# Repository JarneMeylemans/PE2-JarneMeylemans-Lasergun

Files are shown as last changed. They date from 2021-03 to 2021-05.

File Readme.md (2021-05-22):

# Practice Enterprise 2: Lasergun

Jarne Meylemans 

(Finale code staat onder 'Project_Code/STM32F4/PE_LASERGUN_CODE_2apr')

## Korte Beschrijving

Het doel van dit project zal zijn te weten komen hoe een lasergun kan werken. Het geweer zal moeten kunnen een infrarood signaal sturen waarmee het bekend maakt wie het is (Elk geweer heeft zo zijn eigen "code". Elke Lasergun zal met een centraal punt kunnen communiceren om een score bij te houden van het houdige spelletje. 

Via een scherm kan de speler zien hoeveel kogels hij nog heeft en wat zijn score is in het spel. 

## Hardware

Om het lasergeweer te maken heb ik gekozen om met de STM32F410 microcontroller te werken, deze stuurt alles aan als volgt: 

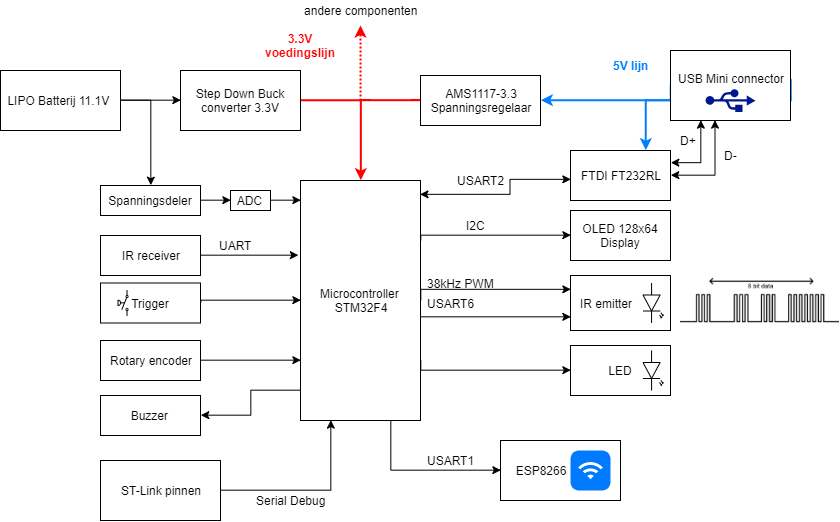
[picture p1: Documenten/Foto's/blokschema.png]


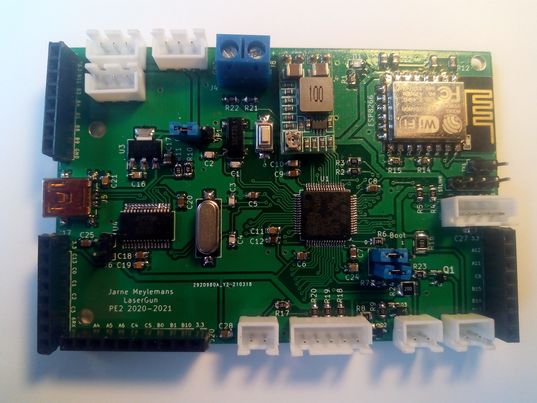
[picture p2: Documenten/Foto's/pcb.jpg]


## Software 

Met de software heb ik geprobeerd om een soort State Machine te programmeren zodat er makkelijk kan veranderd worden van functie waar we inzitten

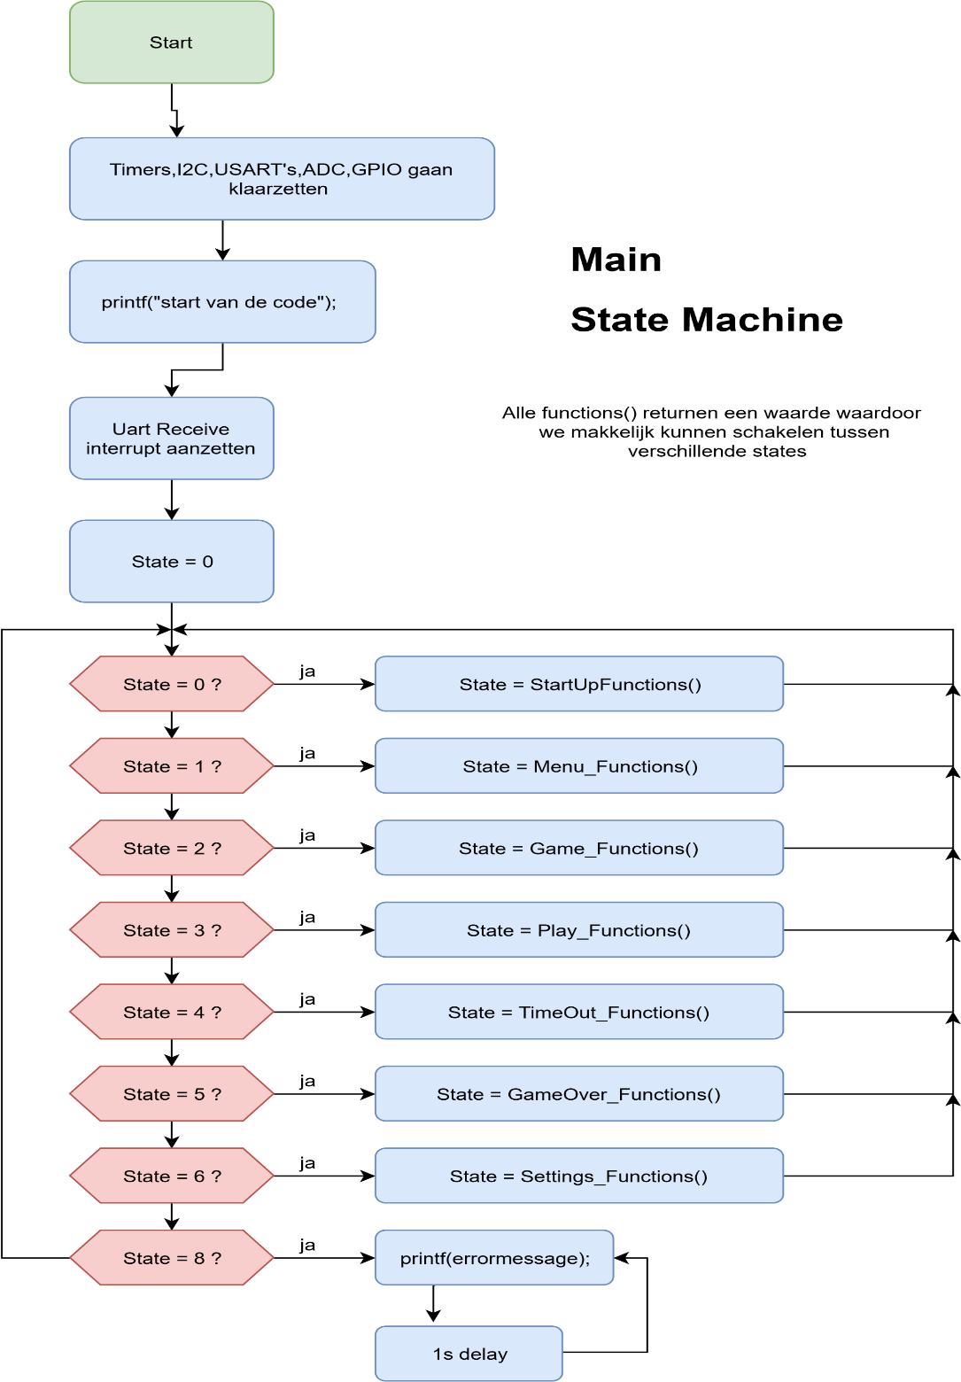
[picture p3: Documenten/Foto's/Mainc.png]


## Behuizing

De behuizing is getekend in fusion 360 en is geprint met een 3D printer, de behuizing bestaat uit 11 verschillende stukken. 

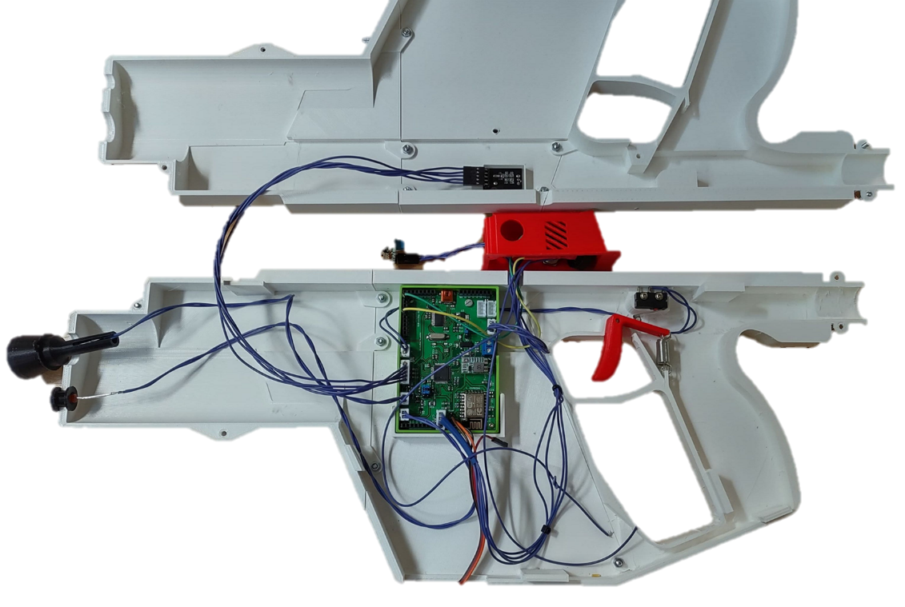
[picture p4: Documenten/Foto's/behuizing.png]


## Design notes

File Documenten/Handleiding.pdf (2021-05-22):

# Lasergeweer: Handleiding

### 1.Aanzetten van het lasergeweer

Er zijn twee opties om het geweer aan te voeding te geven, de eerste is door langs de onderkant de batterij aan te sluiten, de tweede is via een externe powerbank aan te sluiten aan de usb connectie bovenaan het geweer.

Opmerking: Het lasergeweer kan niet meteen afwisselend batterijspanning of USB spanning gebruiken. Om te wisselen tussen spanningsbron is het nodig om het lasergeweer open te schroeven, de blauwe jumper dient naar een andere pin worden gezet.

### 1a. Via batterij

Onderaan het geweer kan de aansluiting van de batterij worden gevonden. Aan de gele XT60 connector kan de batterij worden aangesloten.

Nadien kan de powerswitch gesloten worden om het lasergeweer spanning te geven, deze switch staat bovenaan het lasergeweer.

### 1b. Via USB

Bovenaan het geweer, achter het vizier bevindt zich een mini USB connector. Plug de USB kabel in het lasergeweer, zorg er ook voor dat de USB kabel ook is ingeplugd in een externe powerbank.

### 2. Lasergeweer resetten

Voordat er een spel gestart kan worden moet het lasergeweer even gereset worden. Dit kan door met een dun langwerpige schroevendraaier op de reset knop te drukken.

### 3. Een spel starten

Na het indrukken van de reset knop wordt het startscherm getoond. Om verder te gaan naar het menu dient de rotary encoder switch worden ingedrukt.

In het menu kan er gekozen worden voor 3 dingen, Settings, Play en Exit. Onder het menu ‘settings’ kunnen er enkele parameters aangepast worden voor tijdens het spel. Door ‘Play’ te kiezen wordt het spel gestart. ‘Exit’ gaat je terugbrengen naar het startscherm.

Parameters aanpassen

Onder het settings menu kan de ‘demage’ (schade punten) aangepast worden door de Trigger ingedrukt te houden en aan de rotary encoder te draaien.

Op diezelfde manier kan IR worden aangepast. IR zelf is de ID nummer van het lasergeweer, op die manier kan er gekozen worden of de spelers in teams spelen of individueel. Bij elke ID hoort ook een naam.

### 4. Het spel spelen

Nadat er in het menu gekozen werd voor ‘Play’ gaat het spel opstarten.

De interface tijdens het spelen ziet er als volgt uit

1. Schieten met het lasergeweer kan door de rode trigger over te halen tijdens het spelen.
2. Herladen kan door aan de rotary encoder een bepaalde hoek te draaien, op die manier kunnen er kogels bijgemaakt worden in het geweer.
3. Het spel vroegtijdig afsluiten kan door tijdens het spel op de rotary encoder te klikken.

OLED

Trigger

Rotary
encoder

IR LED

IR ontvanger

Wanneer een speler geraakt is zal het lasergeweer op de display dit tonen samen met een timer van 10 seconden, de speler zal 10 seconden uit het spel liggen, Op het scherm komt te staan door wie je geraakt bent en hoeveel HP er nog over is. Op dat moment word de demage afgetrokken van de huidige HP, wanneer de speler geen Health points meer heeft is het spel voorbij en komt er ‘GAME OVER’ op het scherm.

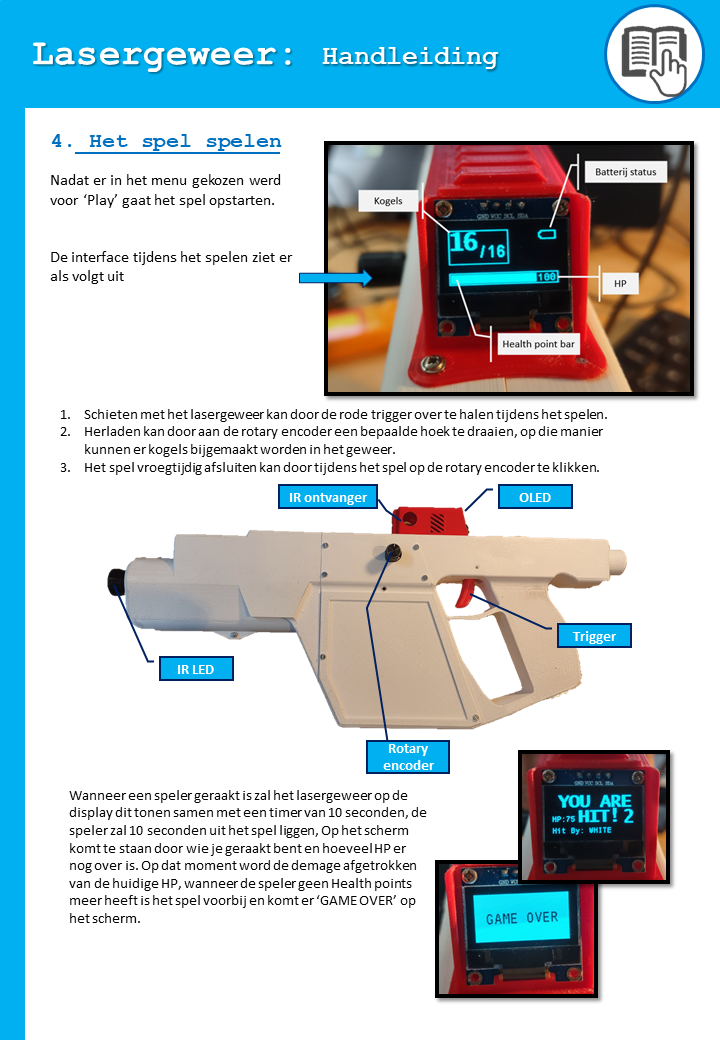
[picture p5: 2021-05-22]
Documenten/Handleiding/Dia3.PNG

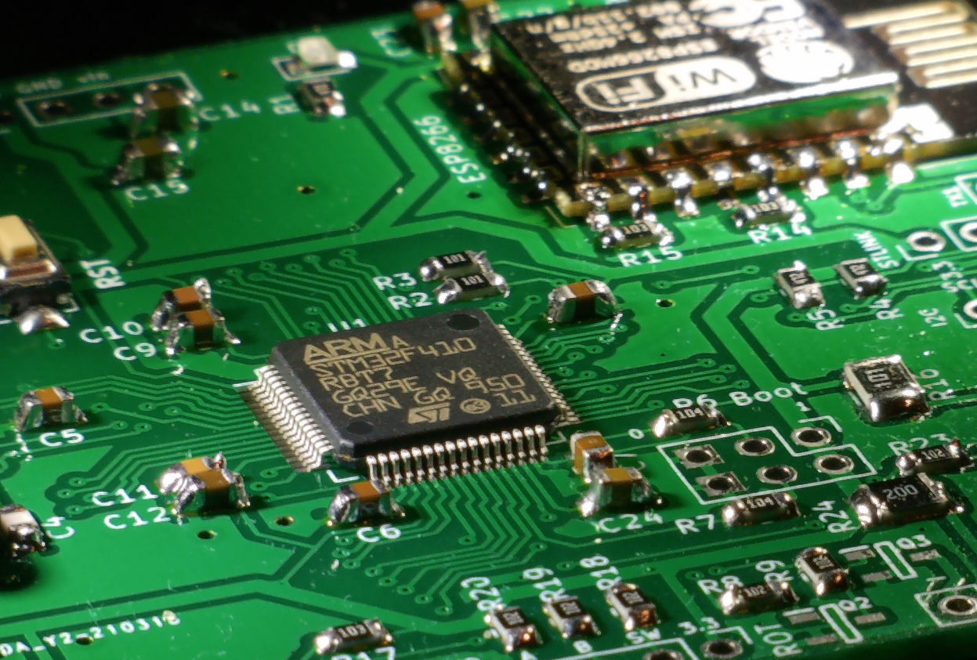
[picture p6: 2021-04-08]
Documenten/Foto's/pcb2.png

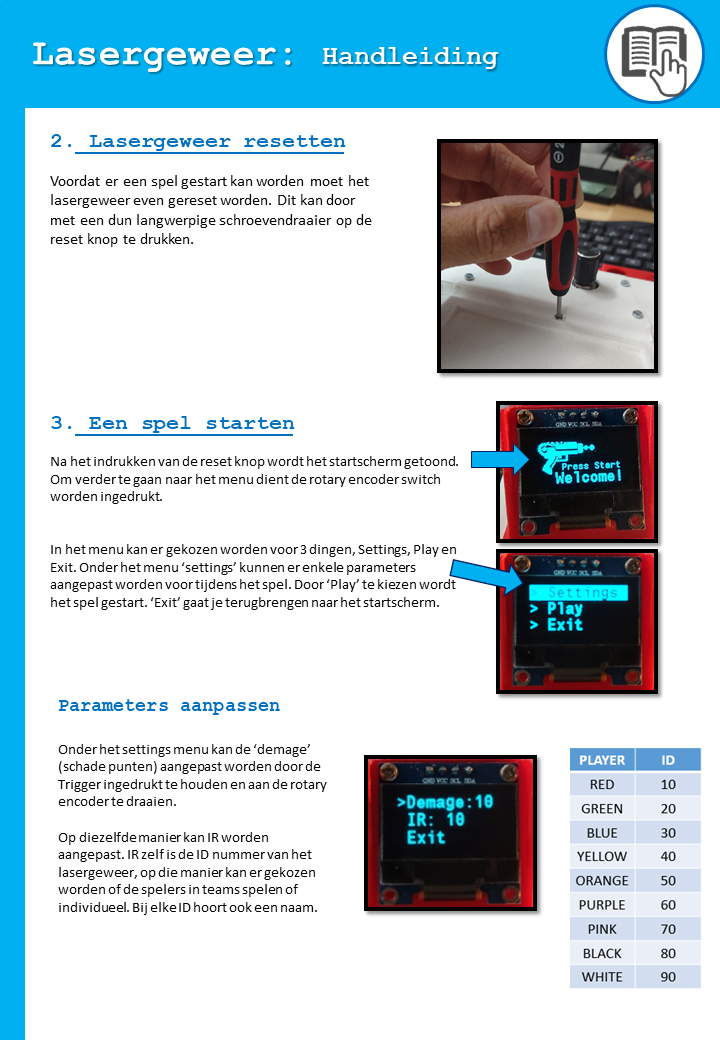
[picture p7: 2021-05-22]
Documenten/Handleiding/Dia2.PNG

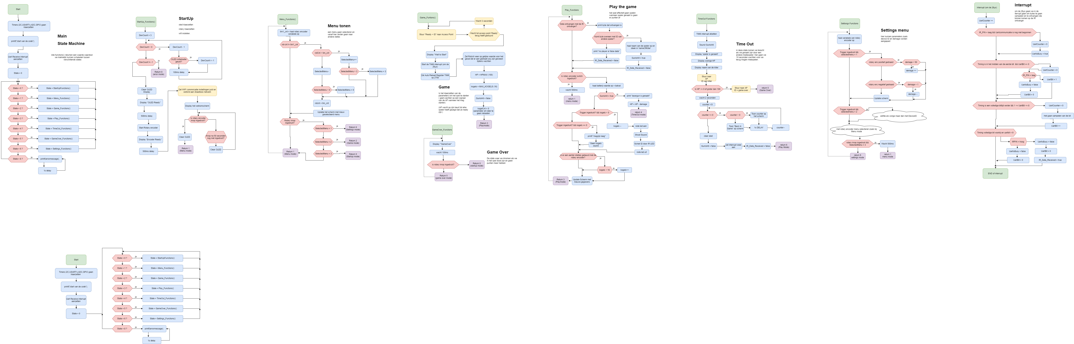
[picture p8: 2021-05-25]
Documenten/SoftwareBlokschema's.png

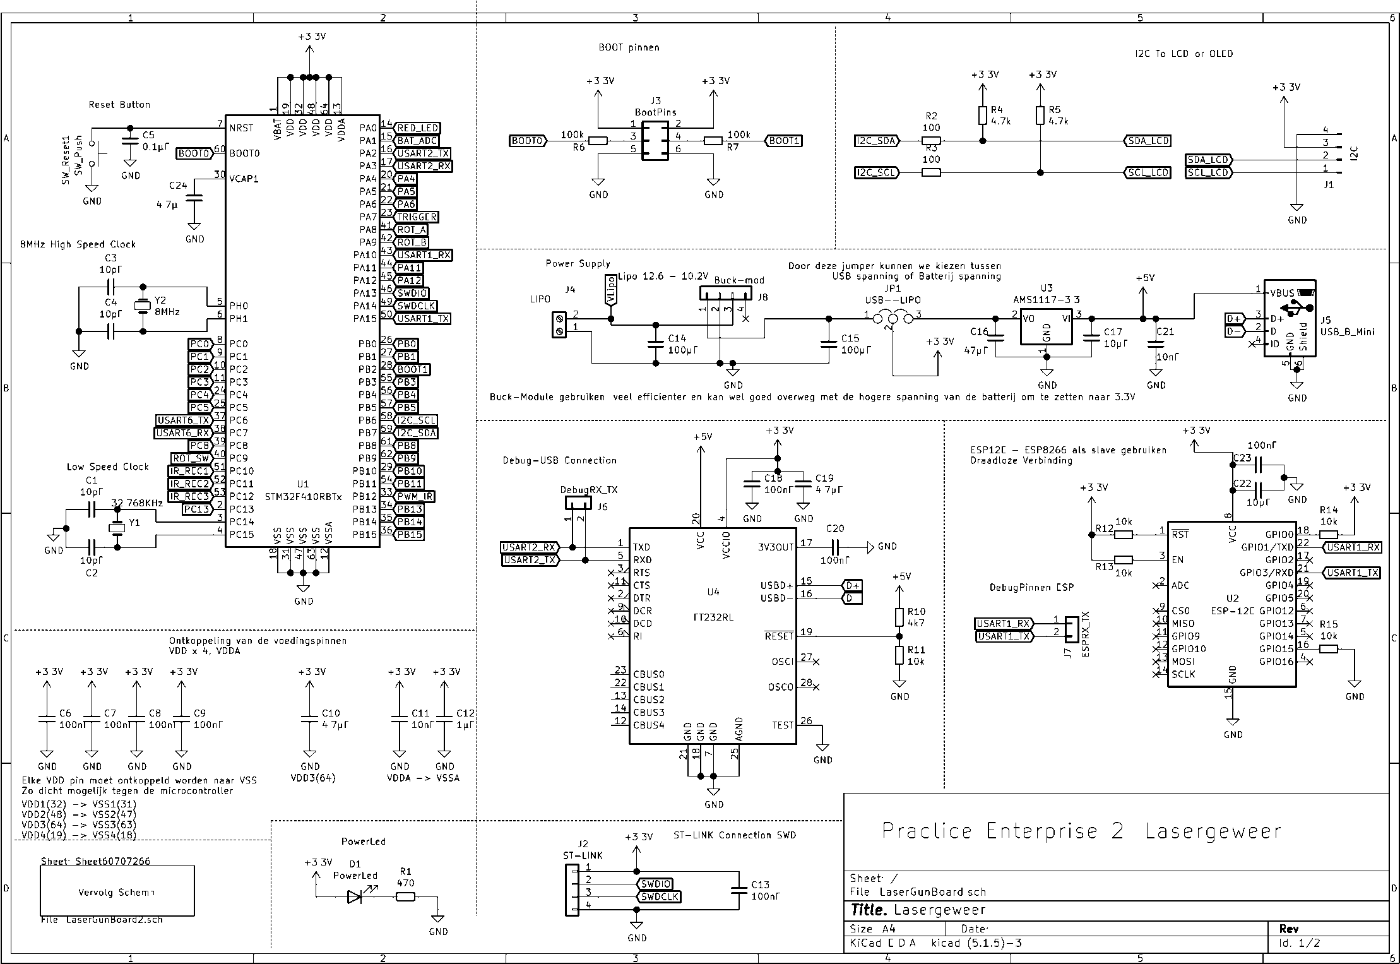
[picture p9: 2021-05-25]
Documenten/Foto's/schema.png

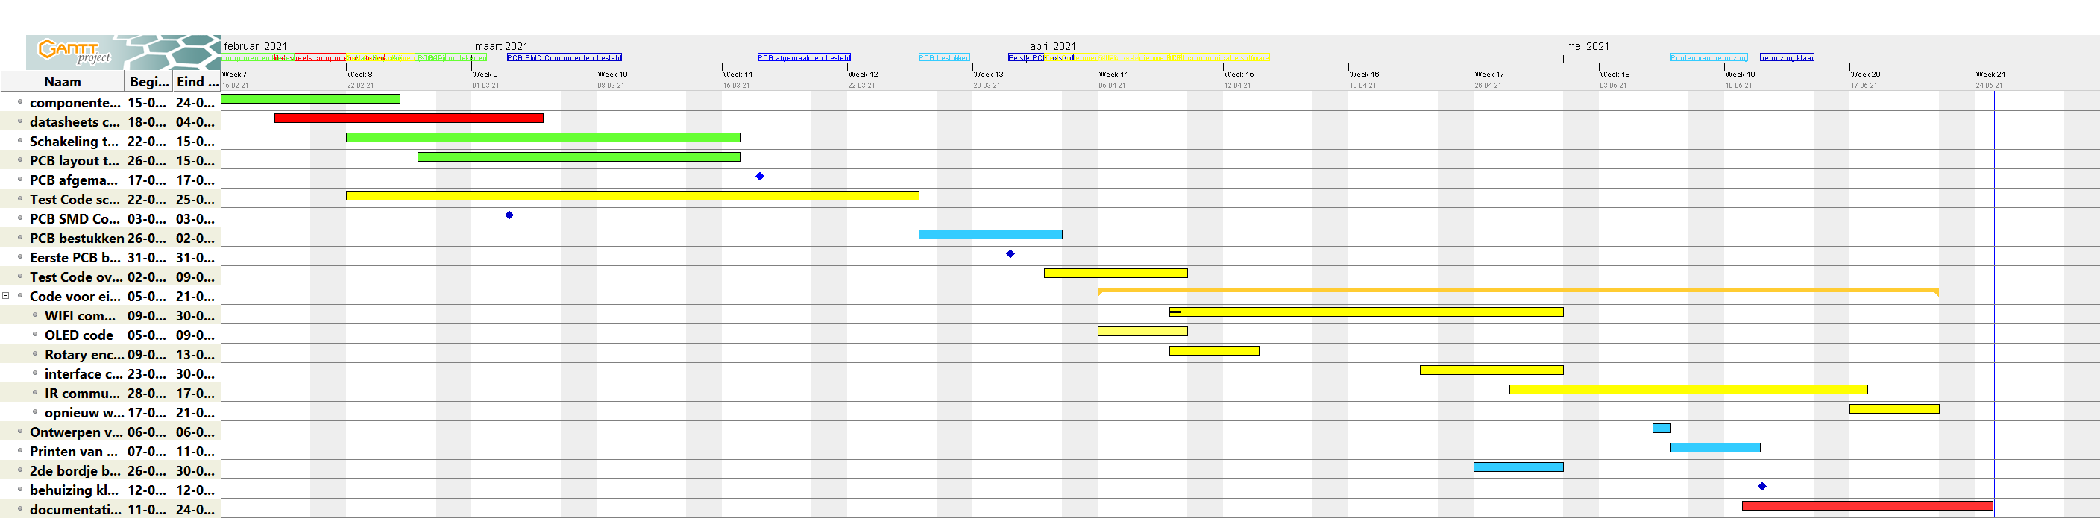
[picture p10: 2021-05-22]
Documenten/gantt/pe2.png

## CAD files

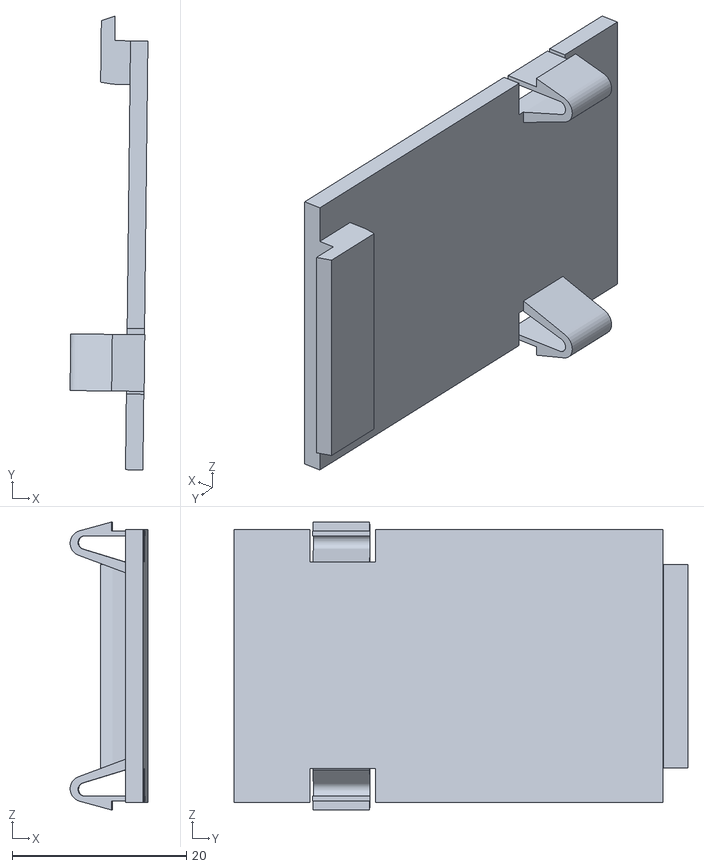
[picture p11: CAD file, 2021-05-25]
3D-tekeningen/batterycover.stl
8.93 x 52.0 x 33.0

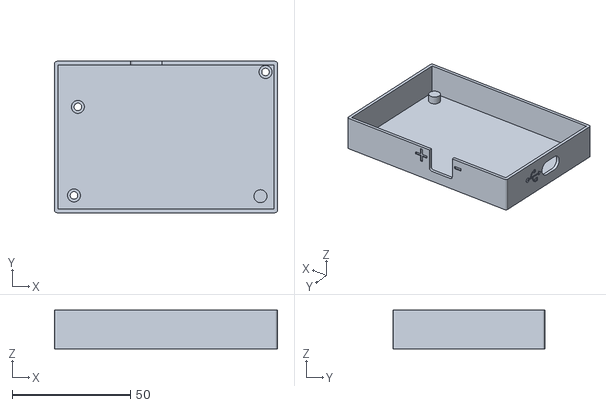
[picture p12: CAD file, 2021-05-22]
3D-tekeningen/LaserBoard_Box.stl
94.2 x 64.0 x 16.3

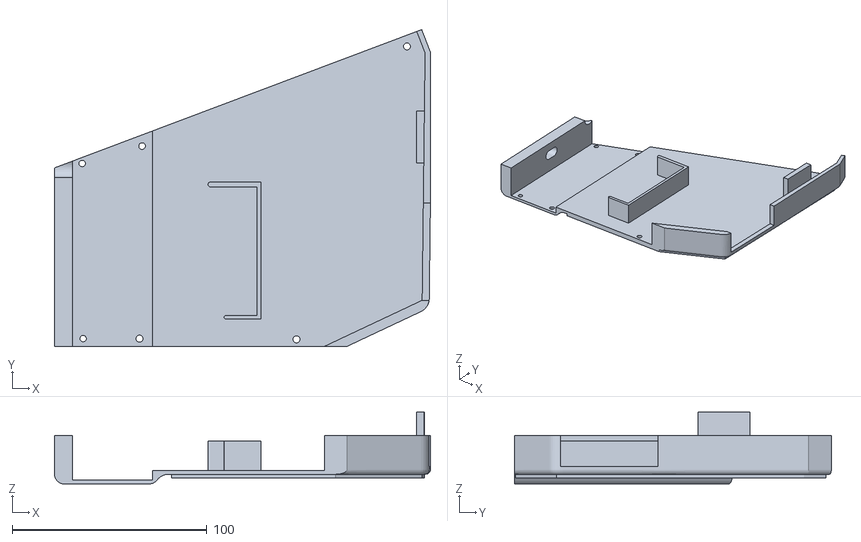
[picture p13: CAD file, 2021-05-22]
3D-tekeningen/midGunR.stl
193.3 x 162.9 x 37.0

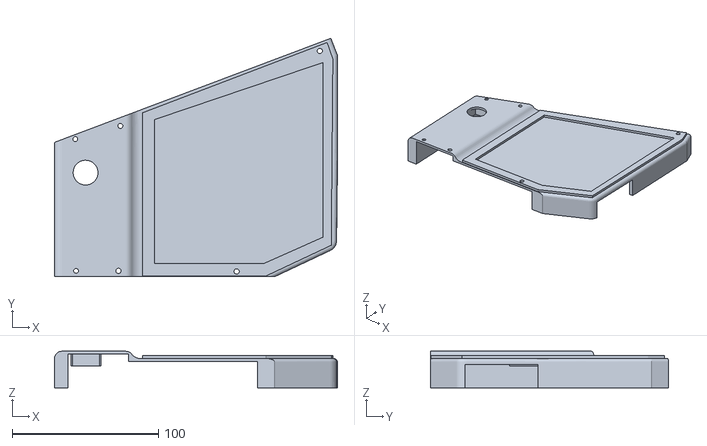
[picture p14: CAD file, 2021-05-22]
3D-tekeningen/midGunL.stl
193.3 x 162.9 x 25.0

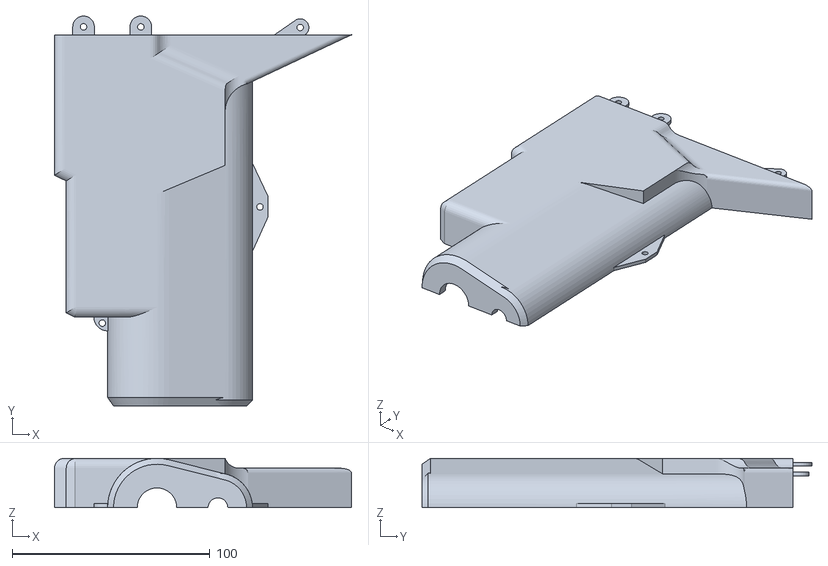
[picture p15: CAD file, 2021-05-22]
3D-tekeningen/barrelL.stl
150.4 x 197.4 x 25.0

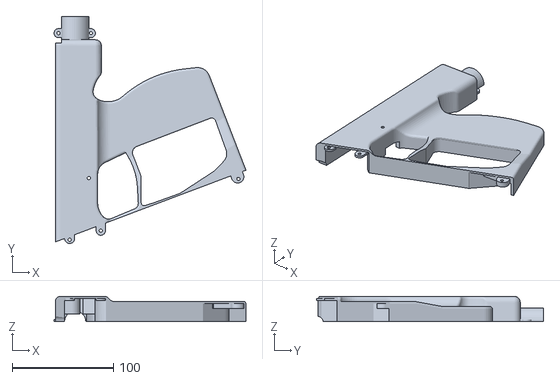
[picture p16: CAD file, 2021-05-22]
3D-tekeningen/endGunL.stl
190.1 x 224.8 x 25.0

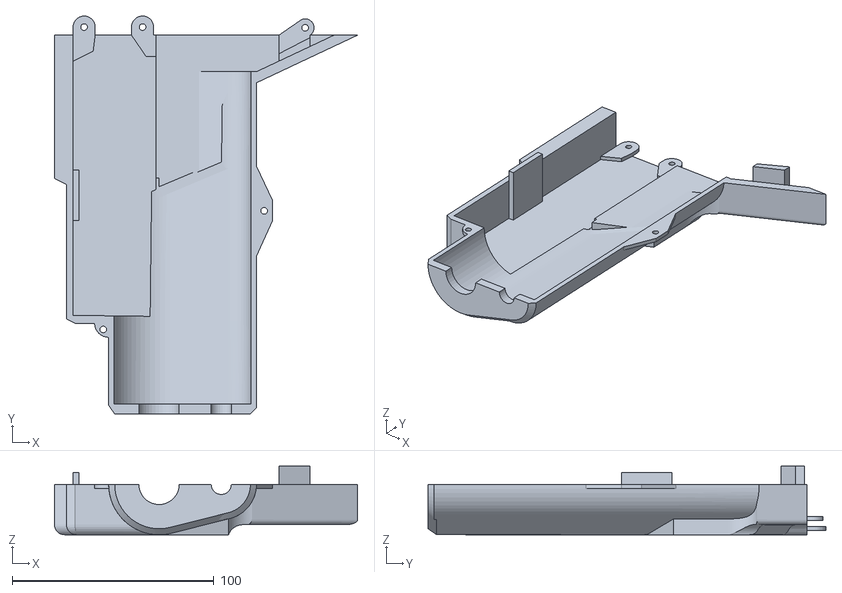
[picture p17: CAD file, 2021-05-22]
3D-tekeningen/barrelR.stl
150.4 x 197.4 x 34.0

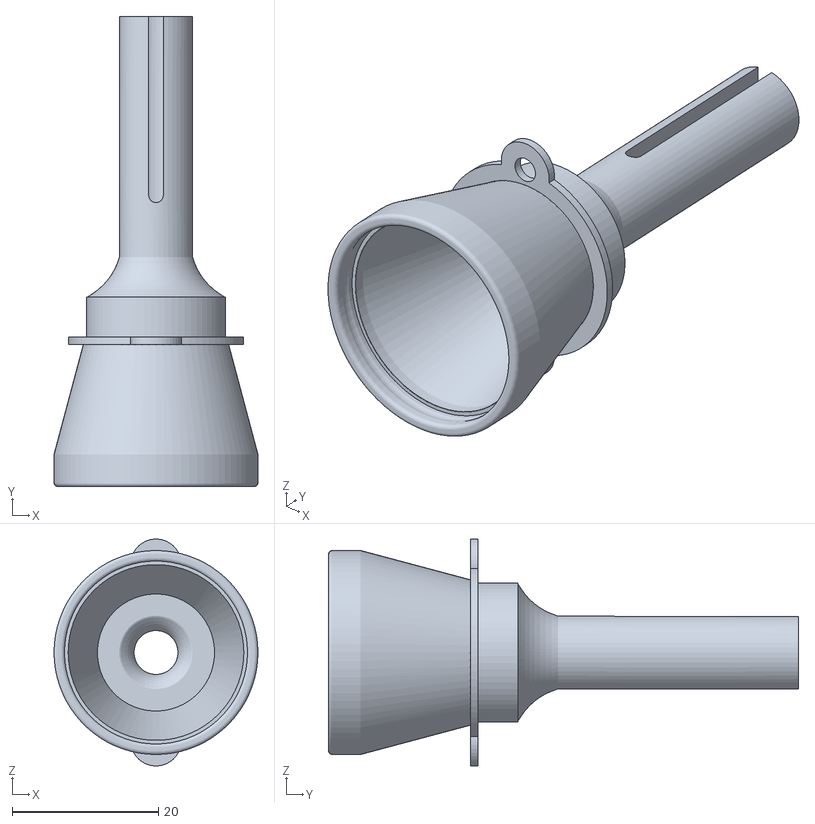
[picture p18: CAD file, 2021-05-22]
3D-tekeningen/IRLEDHOLDER.stl
27.9 x 64.2 x 31.0

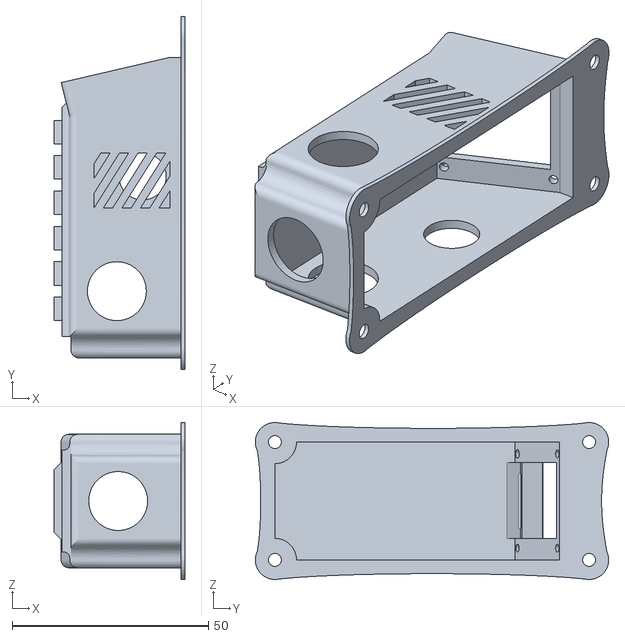
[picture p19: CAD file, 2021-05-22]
3D-tekeningen/VISOR.stl
33.3 x 90.0 x 40.0

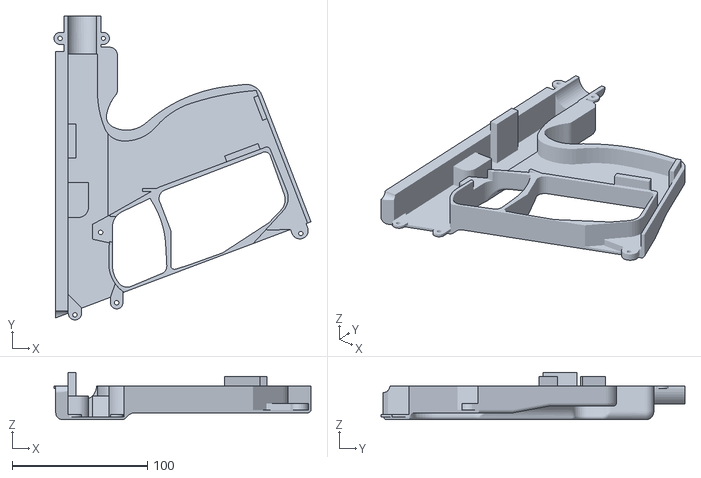
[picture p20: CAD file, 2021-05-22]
3D-tekeningen/endGunR.stl
190.1 x 224.8 x 35.0

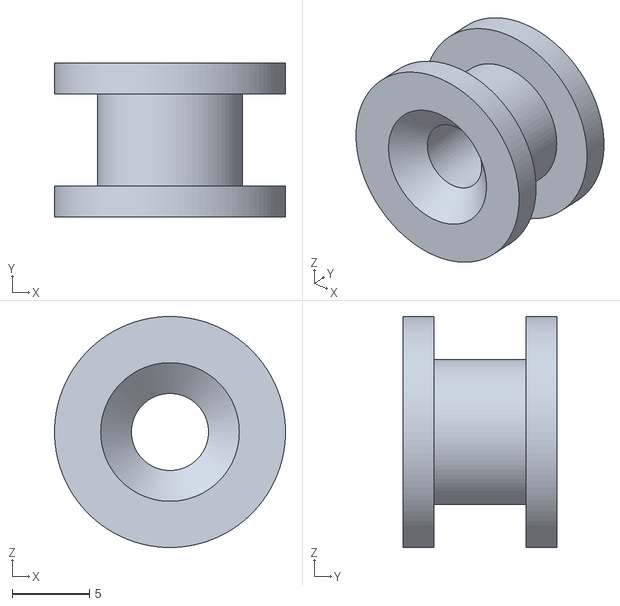
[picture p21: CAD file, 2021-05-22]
3D-tekeningen/LEDHOLDER.stl
15.0 x 10.0 x 15.0

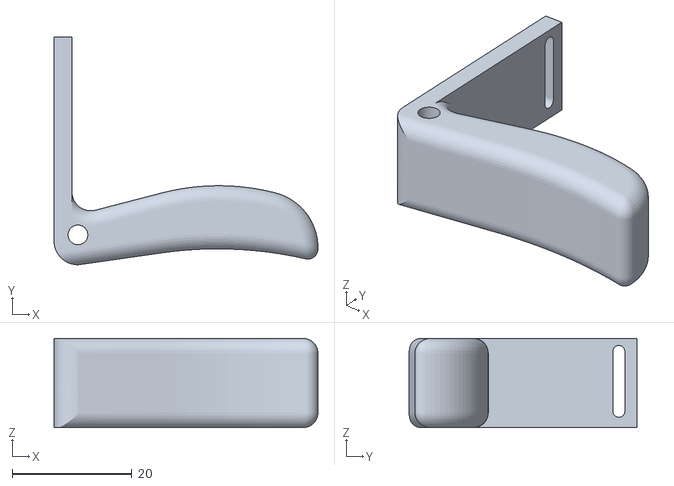
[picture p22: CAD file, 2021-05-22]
3D-tekeningen/trigger.stl
44.1 x 38.0 x 14.9

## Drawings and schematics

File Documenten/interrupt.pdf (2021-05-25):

# Main

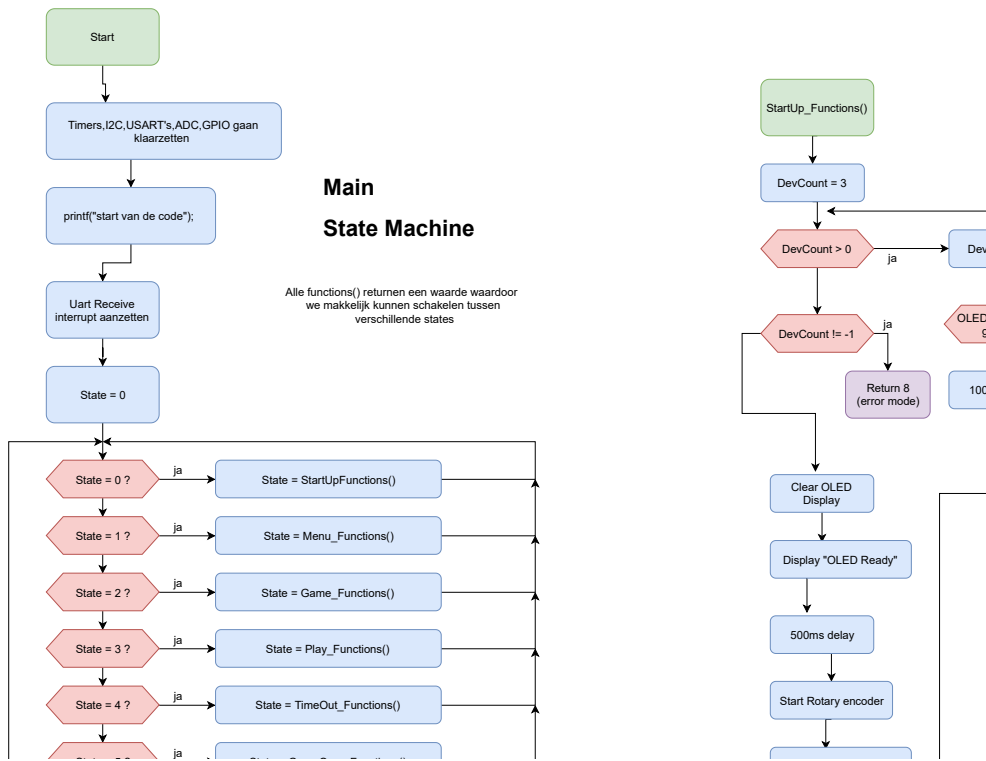
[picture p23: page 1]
Start; klaarzetten; State = 0; State = 0 ?; State = 1 ?; State = 2 ?; State = 3 ?; State = 4 ?; State = StartUpFunctions(); State = Menu_Functions(); State = Game_Functions(); State = Play_Functions(); State = TimeOut_Functions(); State Machine; verschillende states; Uart Receive interrupt aanzetten; StartUp_Functions(); DevCount = 3; DevCount > 0; Dev; OLED g; DevCount != -1; Return 8 (error mode); Clear OLED Display; 500ms delay

Timers,I2C,USART's,ADC,GPIO gaan

printf("start van de code");

Alle functions() returnen een waarde waardoor
we makkelijk kunnen schakelen tussen

Display "OLED Ready"

Start Rotary encoder

# StartUp

# Menu tonen

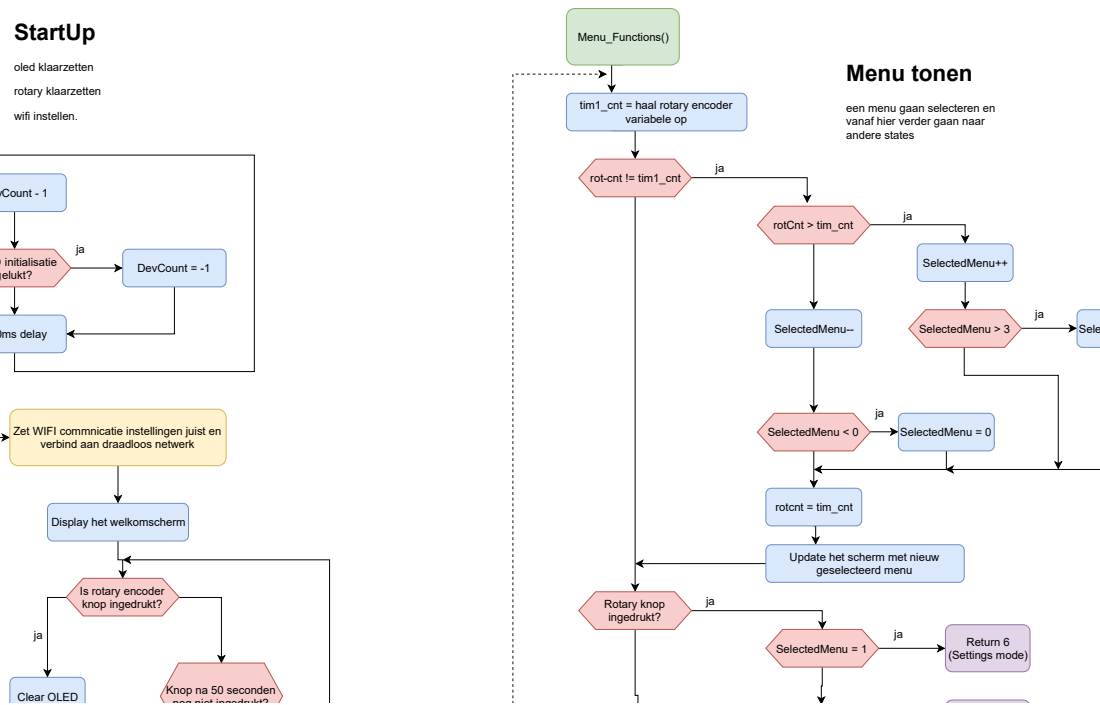
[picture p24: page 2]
vCount - 1; D initialisatie; gelukt?; DevCount = -1; 0ms delay; oled klaarzetten; rotary klaarzetten; wifi instellen.; Menu_Functions(); variabele op; rot-cnt != tim1_cnt; rotCnt > tim_cnt; SelectedMenu++; SelectedMenu--; SelectedMenu > 3; Sele; SelectedMenu < 0; SelectedMenu = 0; rotcnt = tim_cnt; Rotary knop ingedrukt?; SelectedMenu = 1; Return 6; (Settings mode)

tim1_cnt = haal rotary encoder

een menu gaan selecteren en
vanaf hier verder gaan naar
andere states

Zet WIFI commnicatie instellingen juist en
verbind aan draadloos netwerk

Display het welkomscherm

Update het scherm met nieuw
geselecteerd menu

Is rotary encoder
knop ingedrukt?

nog niet ingedrukt? Clear OLED

Knop na 50 seconden

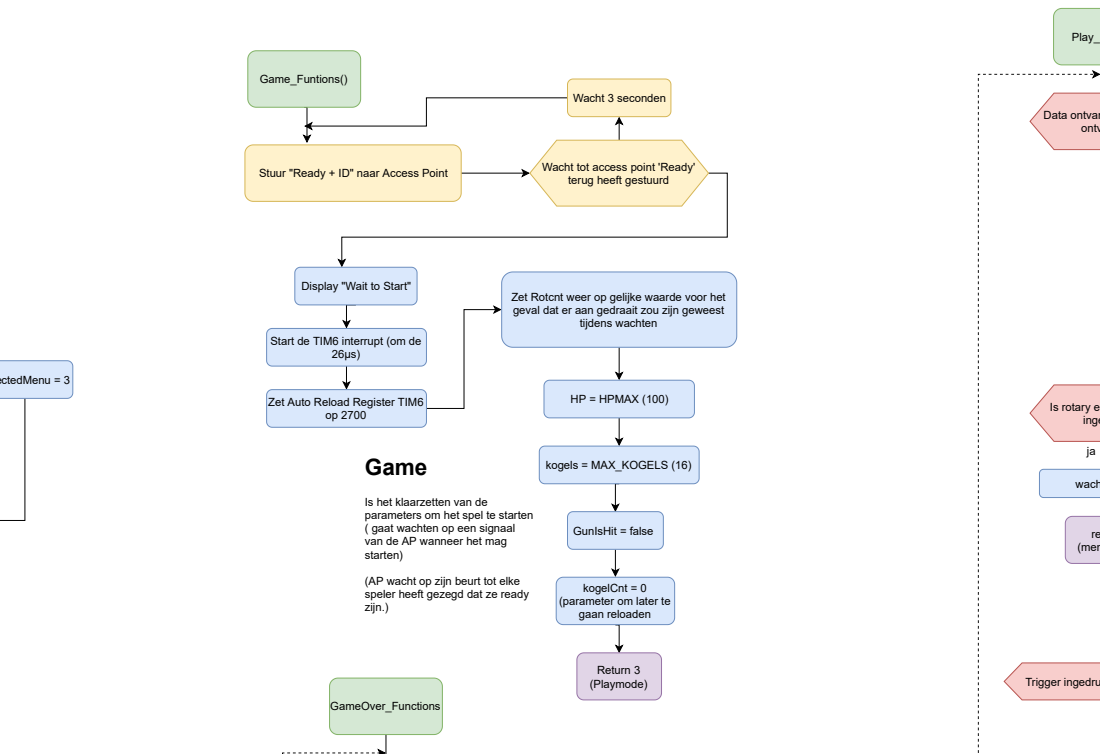
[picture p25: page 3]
ectedMenu = 3; Game_Funtions(); Stuur "Ready + ID" naar Access Point; Wacht tot access point 'Ready'; Wacht 3 seconden; tijdens wachten; HP = HPMAX (100); kogels = MAX_KOGELS (16); GunIsHit = false; Return 3 (Playmode); Game; Play_; Data ontvan ontv; Is rotary e inge; wach; re (men; Trigger ingedru; GameOver_Functions

terug heeft gestuurd

Display "Wait to Start"

Zet Rotcnt weer op gelijke waarde voor het
geval dat er aan gedraait zou zijn geweest

Start de TIM6 interrupt (om de

Zet Auto Reload Register TIM6

Is het klaarzetten van de
parameters om het spel te starten
( gaat wachten op een signaal
van de AP wanneer het mag
starten)

(AP wacht op zijn beurt tot elke
speler heeft gezegd dat ze ready
zijn.)

kogelCnt = 0
(parameter om later te
gaan reloaden

# Play the game

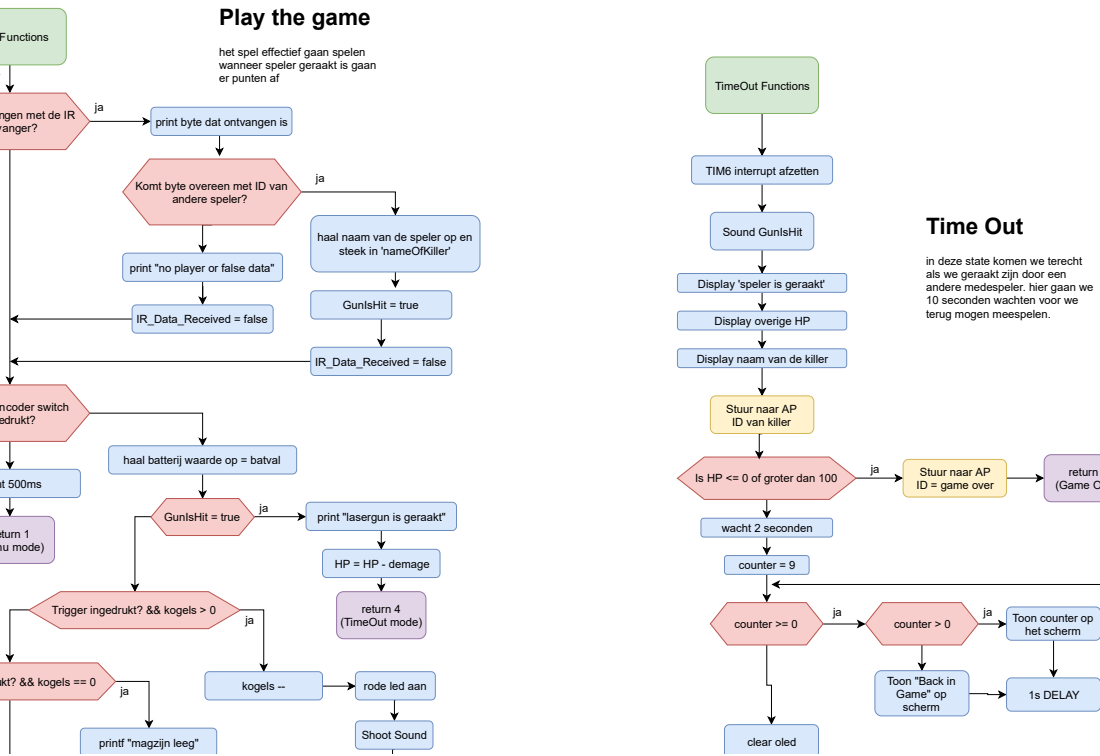
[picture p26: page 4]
_Functions; vanger?; print byte dat ontvangen is; IR_Data_Received = false; ncoder switch edrukt?; GunIsHit = true; eturn 1 nu mode); print "lasergun is geraakt"; return 4 (TimeOut mode); ukt? && kogels == 0; kogels --; rode led aan; TimeOut Functions; TIM6 interrupt afzetten; Sound GunIsHit; return (Game O; wacht 2 seconden; counter = 9; counter >= 0; counter > 0; Toon counter op; het scherm; 1s DELAY; clear oled; Time Out

het spel effectief gaan spelen
wanneer speler geraakt is gaan
er punten af

ngen met de IR

Komt byte overeen met ID van
andere speler?

haal naam van de speler op en
steek in 'nameOfKiller'

print "no player or false data"

in deze state komen we terecht
als we geraakt zijn door een
andere medespeler. hier gaan we
10 seconden wachten voor we
terug mogen meespelen.

Display 'speler is geraakt'

Display overige HP

Display naam van de killer

Stuur naar AP
ID van killer

haal batterij waarde op = batval

ID = game over

Is HP <= 0 of groter dan 100

HP = HP - demage

Trigger ingedrukt? && kogels > 0

Toon "Back in
Game" op
scherm

Shoot Sound printf "magzijn leeg"
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

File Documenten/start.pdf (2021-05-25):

# Main

Start; klaarzetten; State = 0; State = 0 ?; State = 1 ?; State = 2 ?; State = 3 ?; State = 4 ?; State = StartUpFunctions(); State = Menu_Functions(); State = Game_Functions(); State = Play_Functions(); State = TimeOut_Functions(); State Machine; verschillende states; Uart Receive interrupt aanzetten; StartUp_Functions(); DevCount = 3; DevCount > 0; Dev; OLED g; DevCount != -1; Return 8 (error mode); Clear OLED Display; 500ms delay

Timers,I2C,USART's,ADC,GPIO gaan

printf("start van de code");

Alle functions() returnen een waarde waardoor
we makkelijk kunnen schakelen tussen

Display "OLED Ready"

Start Rotary encoder

# StartUp

# Menu tonen

vCount - 1; D initialisatie; gelukt?; DevCount = -1; 0ms delay; oled klaarzetten; rotary klaarzetten; wifi instellen.; Menu_Functions(); variabele op; rot-cnt != tim1_cnt; rotCnt > tim_cnt; SelectedMenu++; SelectedMenu--; SelectedMenu > 3; Sele; SelectedMenu < 0; SelectedMenu = 0; rotcnt = tim_cnt; Rotary knop ingedrukt?; SelectedMenu = 1; Return 6; (Settings mode)

tim1_cnt = haal rotary encoder

een menu gaan selecteren en
vanaf hier verder gaan naar
andere states

Zet WIFI commnicatie instellingen juist en
verbind aan draadloos netwerk

Display het welkomscherm

Update het scherm met nieuw
geselecteerd menu

Is rotary encoder
knop ingedrukt?

nog niet ingedrukt? Clear OLED

Knop na 50 seconden

ectedMenu = 3; Game_Funtions(); Stuur "Ready + ID" naar Access Point; Wacht tot access point 'Ready'; Wacht 3 seconden; tijdens wachten; HP = HPMAX (100); kogels = MAX_KOGELS (16); GunIsHit = false; Return 3 (Playmode); Game; Play_; Data ontvan ontv; Is rotary e inge; wach; re (men; Trigger ingedru; GameOver_Functions

terug heeft gestuurd

Display "Wait to Start"

Zet Rotcnt weer op gelijke waarde voor het
geval dat er aan gedraait zou zijn geweest

Start de TIM6 interrupt (om de

Zet Auto Reload Register TIM6

Is het klaarzetten van de
parameters om het spel te starten
( gaat wachten op een signaal
van de AP wanneer het mag
starten)

(AP wacht op zijn beurt tot elke
speler heeft gezegd dat ze ready
zijn.)

kogelCnt = 0
(parameter om later te
gaan reloaden

# Play the game

_Functions; vanger?; print byte dat ontvangen is; IR_Data_Received = false; ncoder switch edrukt?; GunIsHit = true; eturn 1 nu mode); print "lasergun is geraakt"; return 4 (TimeOut mode); ukt? && kogels == 0; kogels --; rode led aan; TimeOut Functions; TIM6 interrupt afzetten; Sound GunIsHit; return (Game O; wacht 2 seconden; counter = 9; counter >= 0; counter > 0; Toon counter op; het scherm; 1s DELAY; clear oled; Time Out

het spel effectief gaan spelen
wanneer speler geraakt is gaan
er punten af

ngen met de IR

Komt byte overeen met ID van
andere speler?

haal naam van de speler op en
steek in 'nameOfKiller'

print "no player or false data"

in deze state komen we terecht
als we geraakt zijn door een
andere medespeler. hier gaan we
10 seconden wachten voor we
terug mogen meespelen.

Display 'speler is geraakt'

Display overige HP

Display naam van de killer

Stuur naar AP
ID van killer

haal batterij waarde op = batval

ID = game over

Is HP <= 0 of groter dan 100

HP = HP - demage

Trigger ingedrukt? && kogels > 0

Toon "Back in
Game" op
scherm

Shoot Sound printf "magzijn leeg"
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

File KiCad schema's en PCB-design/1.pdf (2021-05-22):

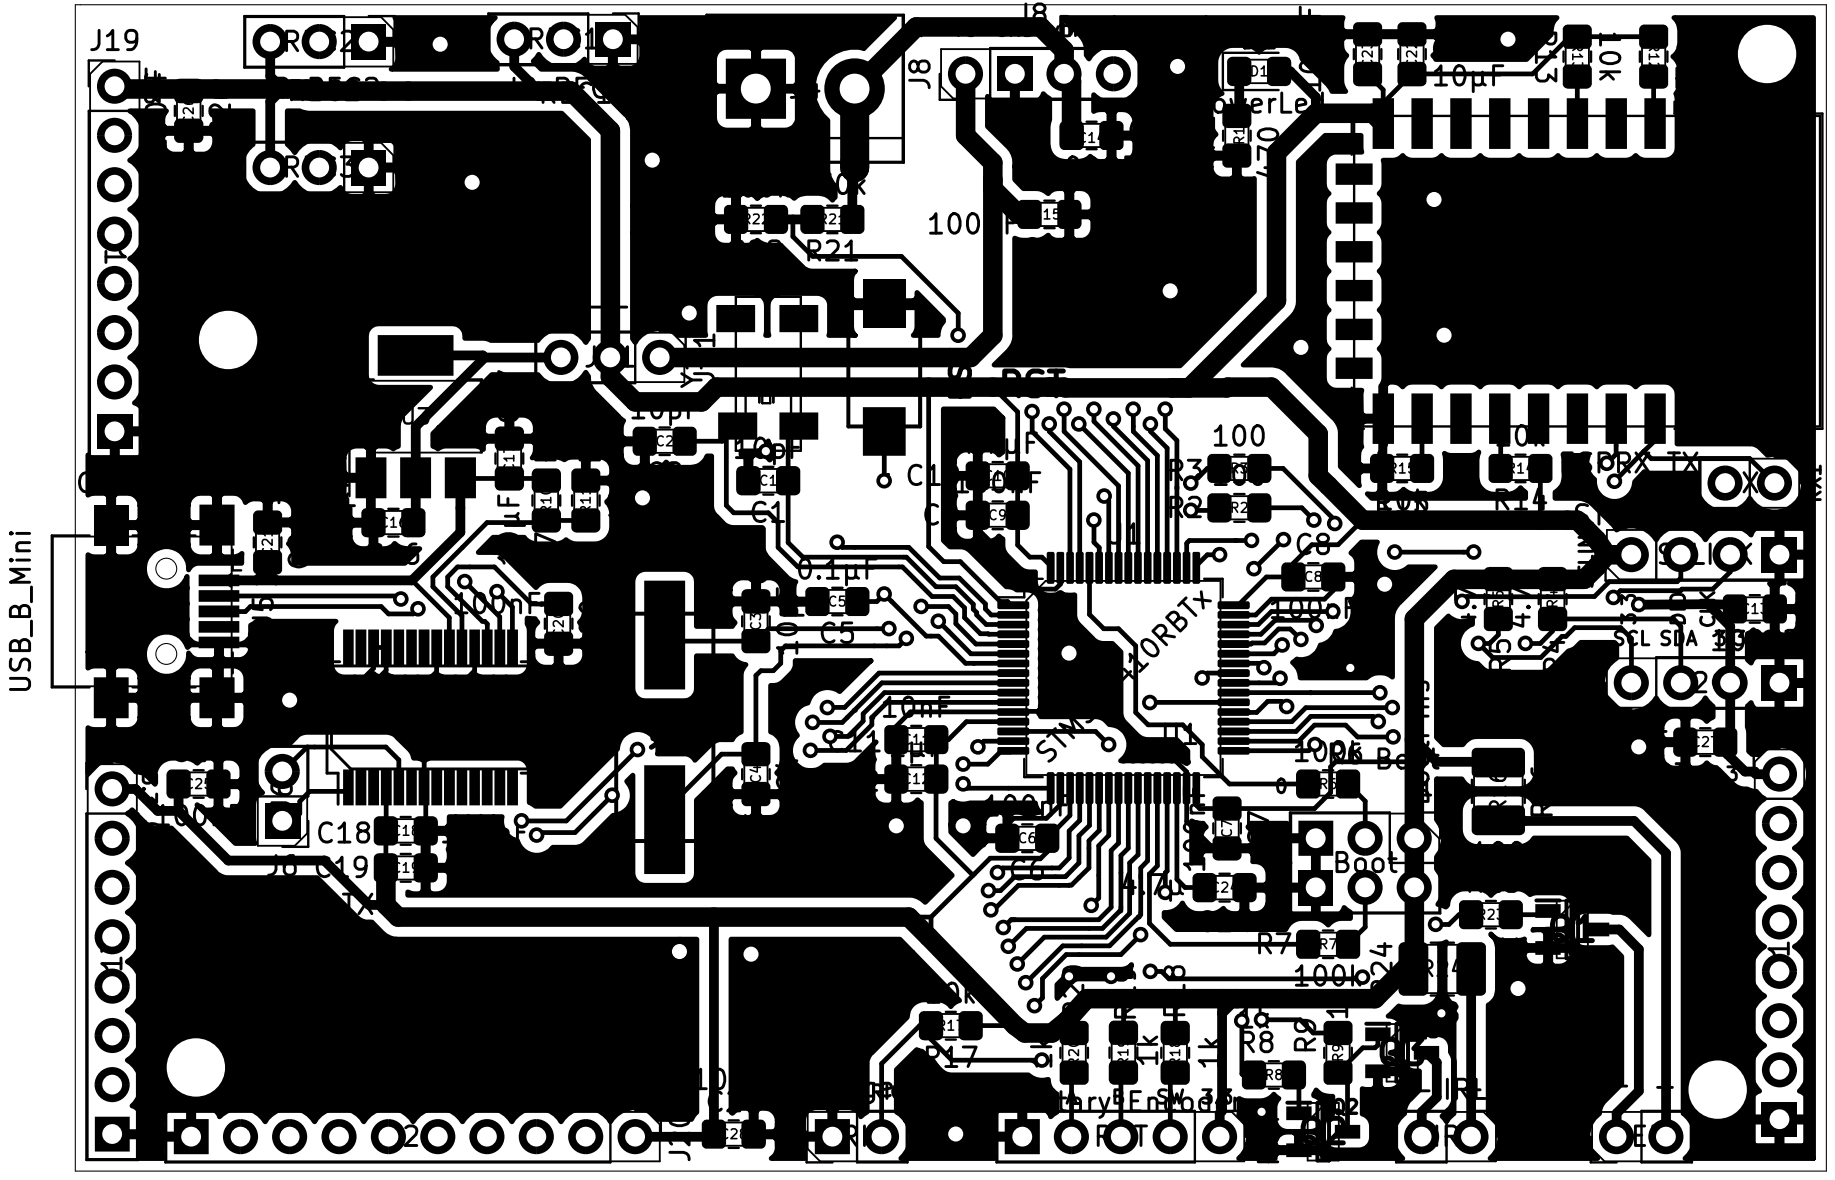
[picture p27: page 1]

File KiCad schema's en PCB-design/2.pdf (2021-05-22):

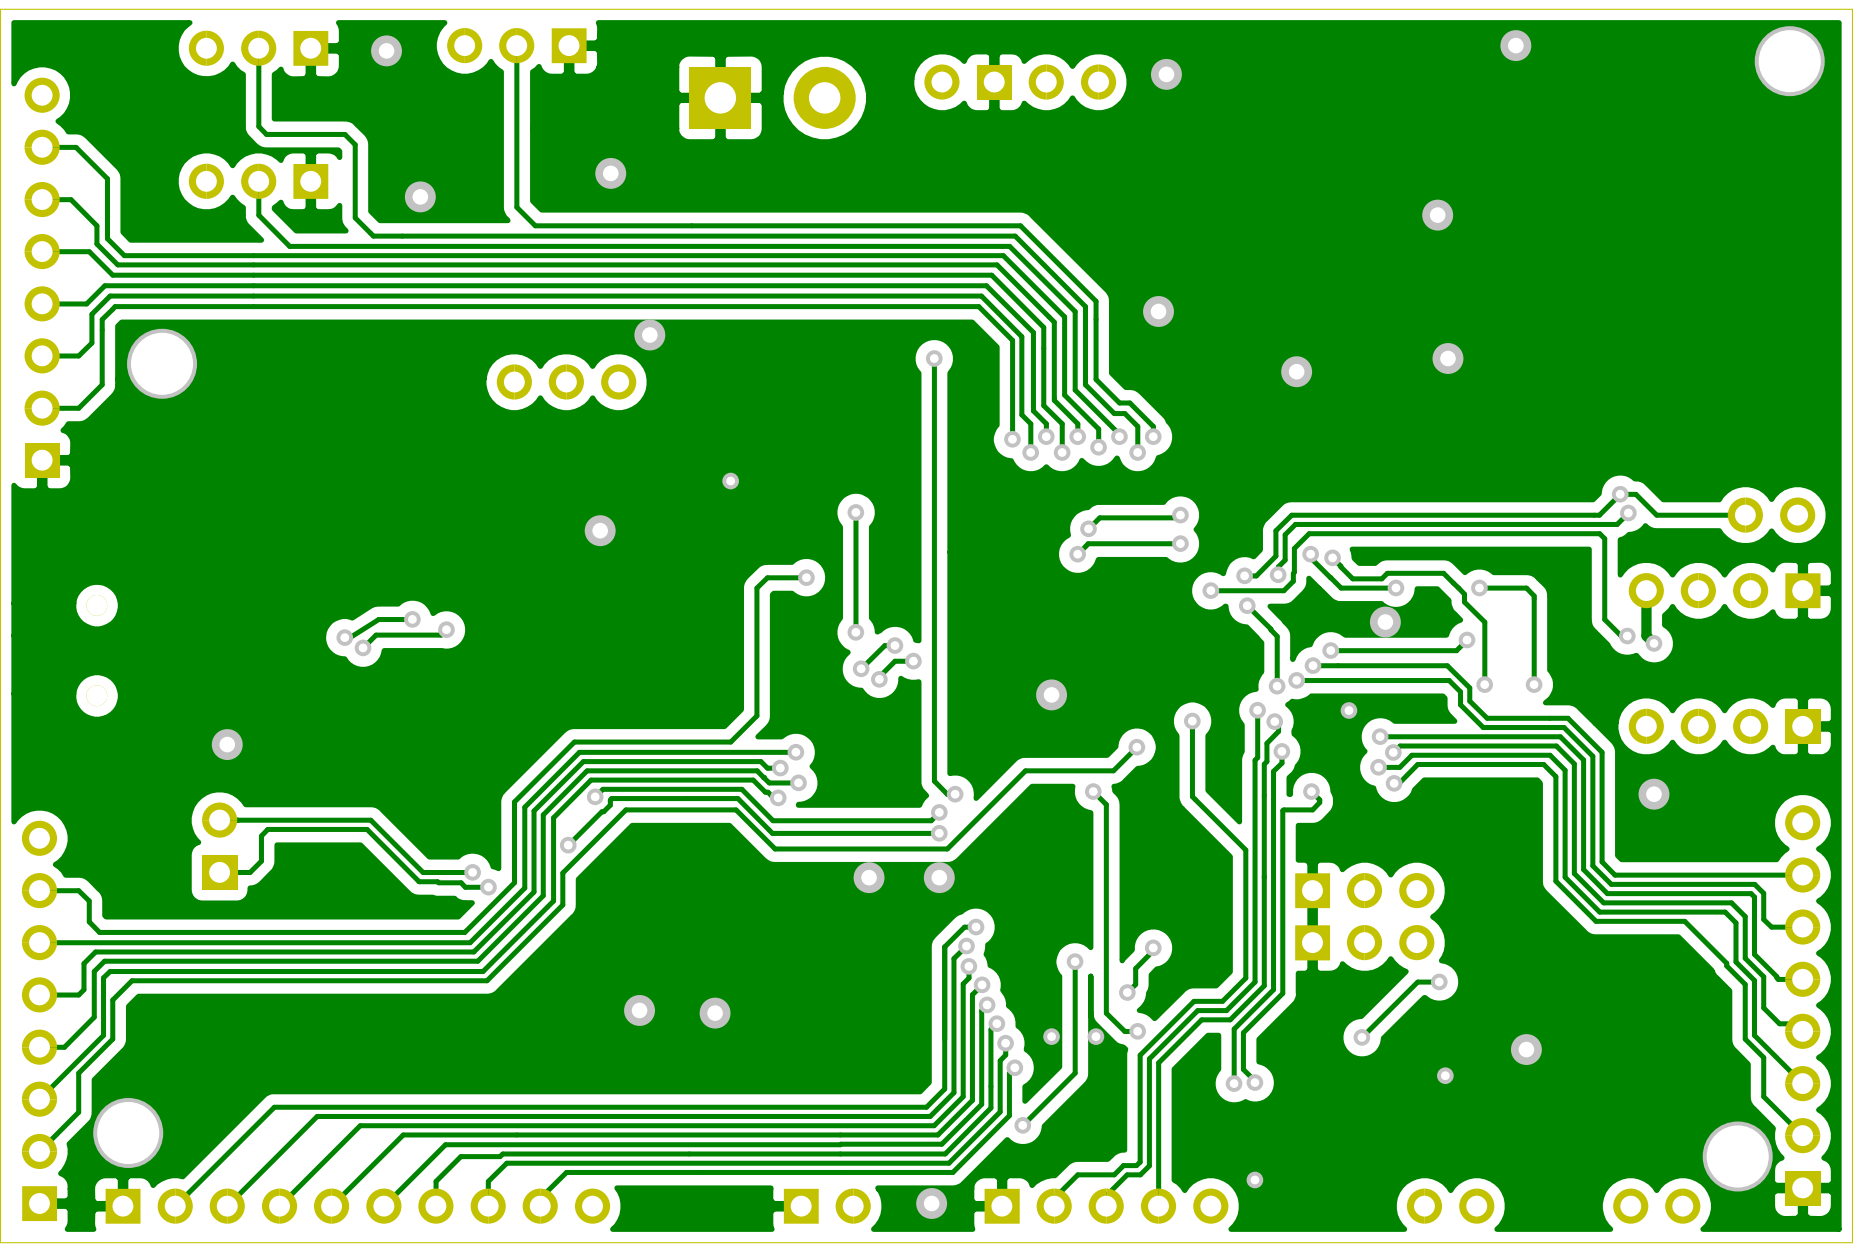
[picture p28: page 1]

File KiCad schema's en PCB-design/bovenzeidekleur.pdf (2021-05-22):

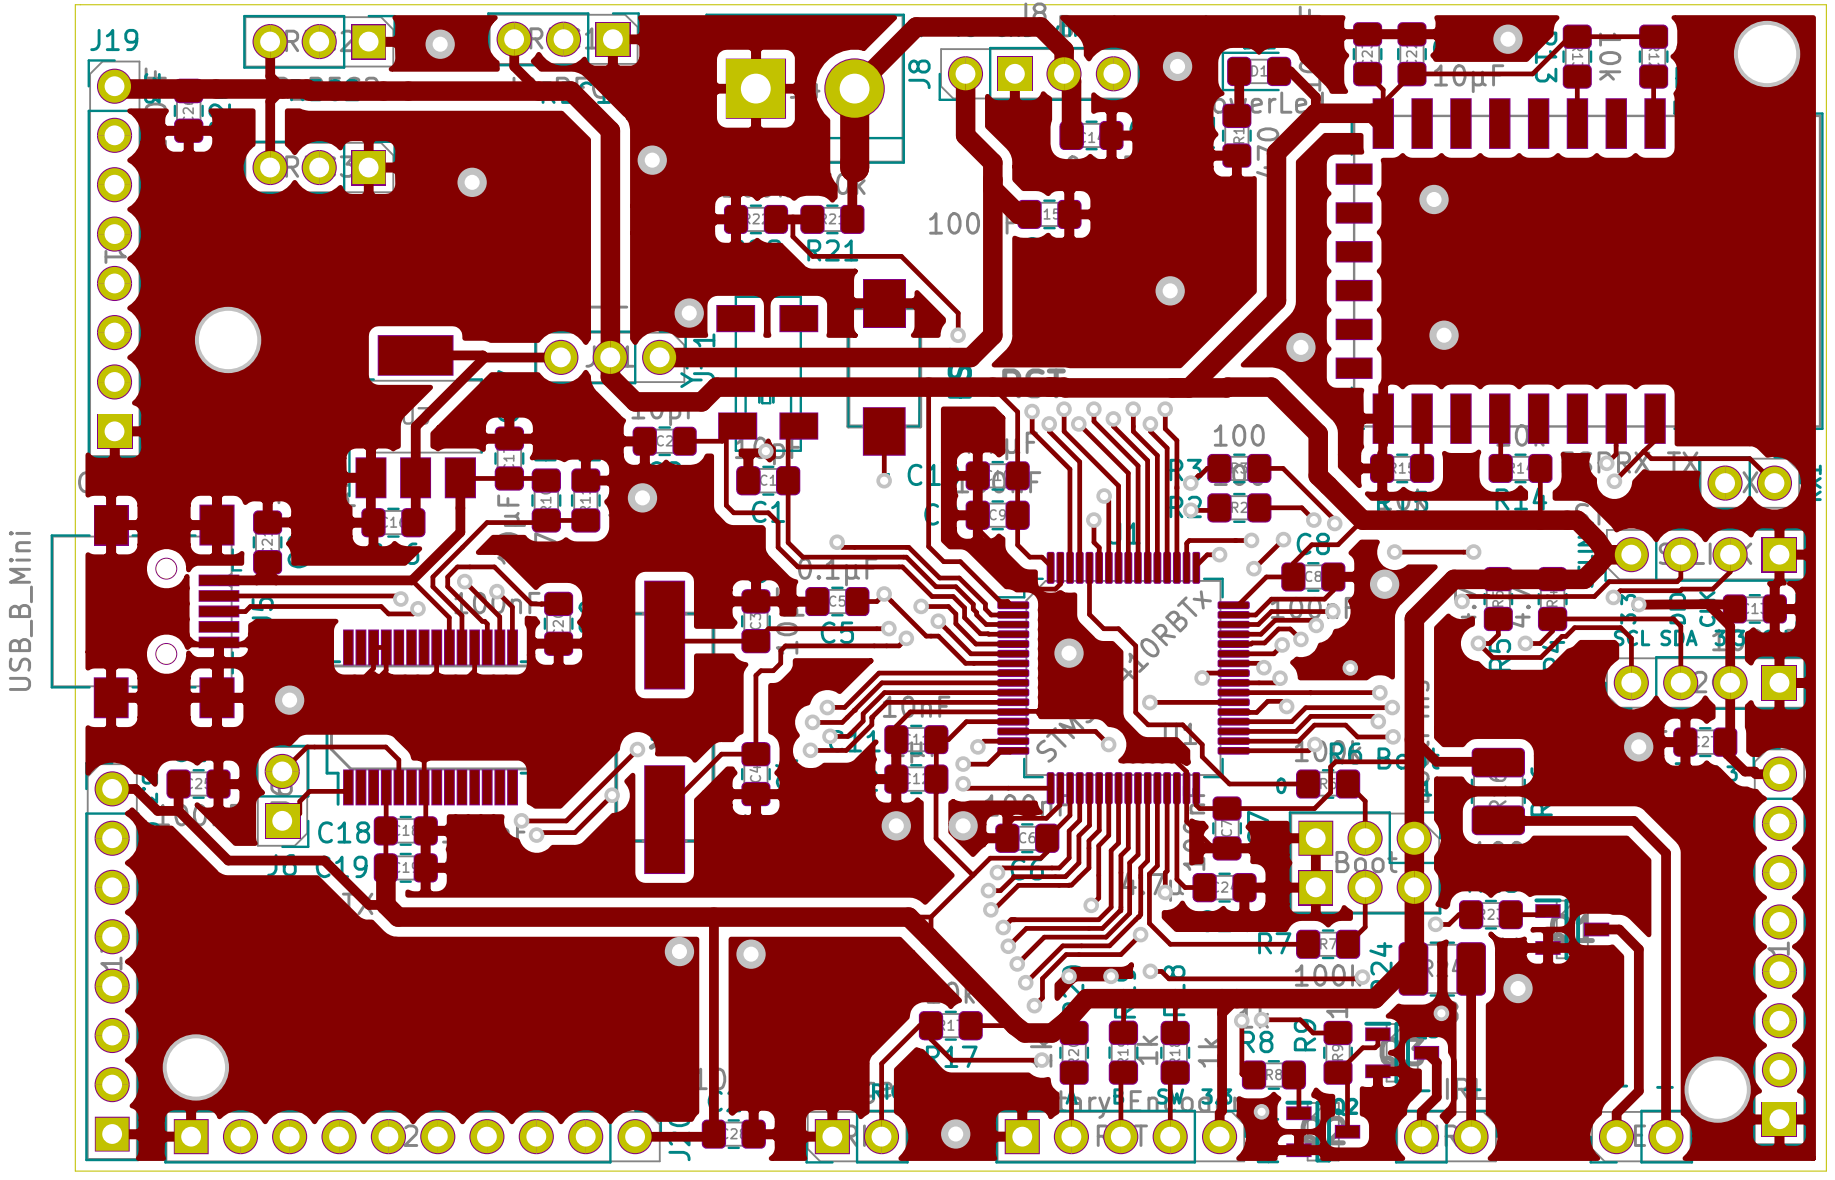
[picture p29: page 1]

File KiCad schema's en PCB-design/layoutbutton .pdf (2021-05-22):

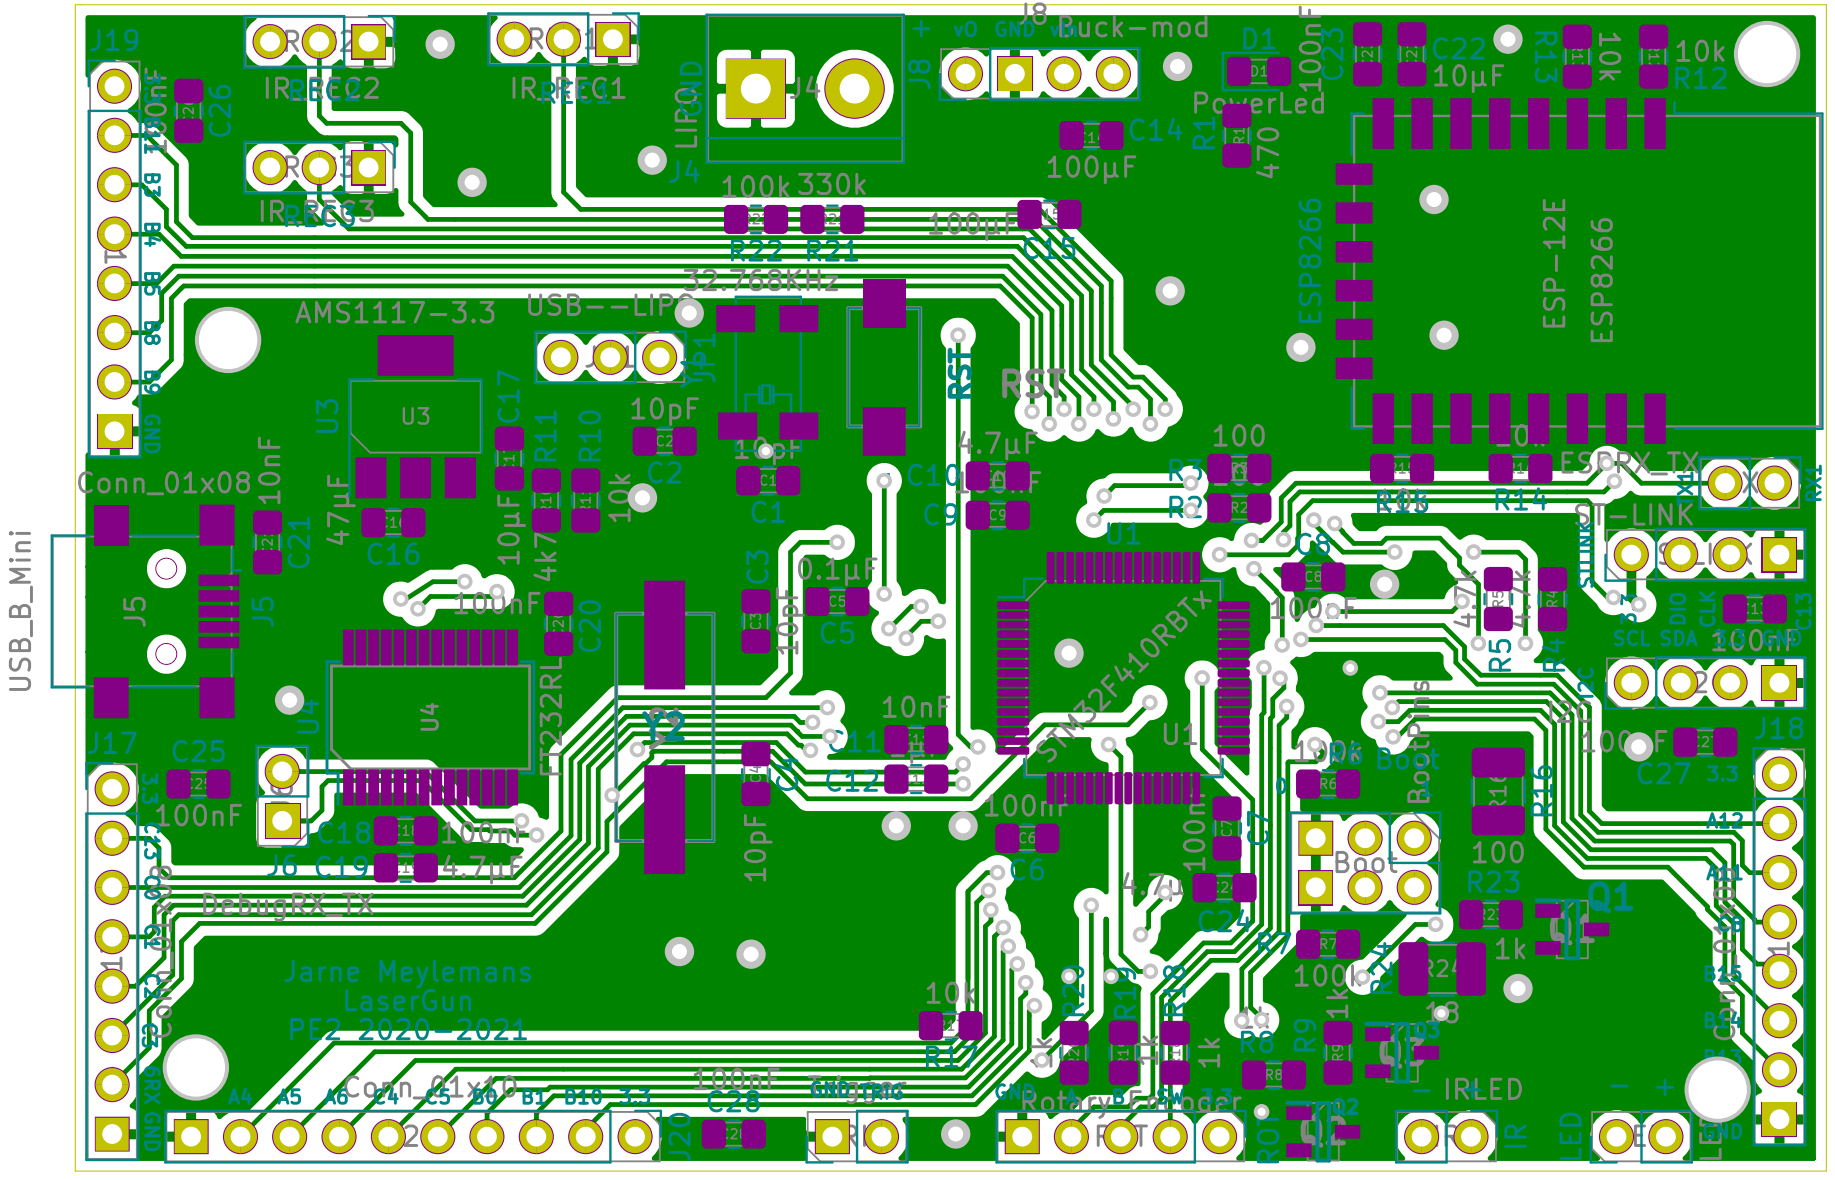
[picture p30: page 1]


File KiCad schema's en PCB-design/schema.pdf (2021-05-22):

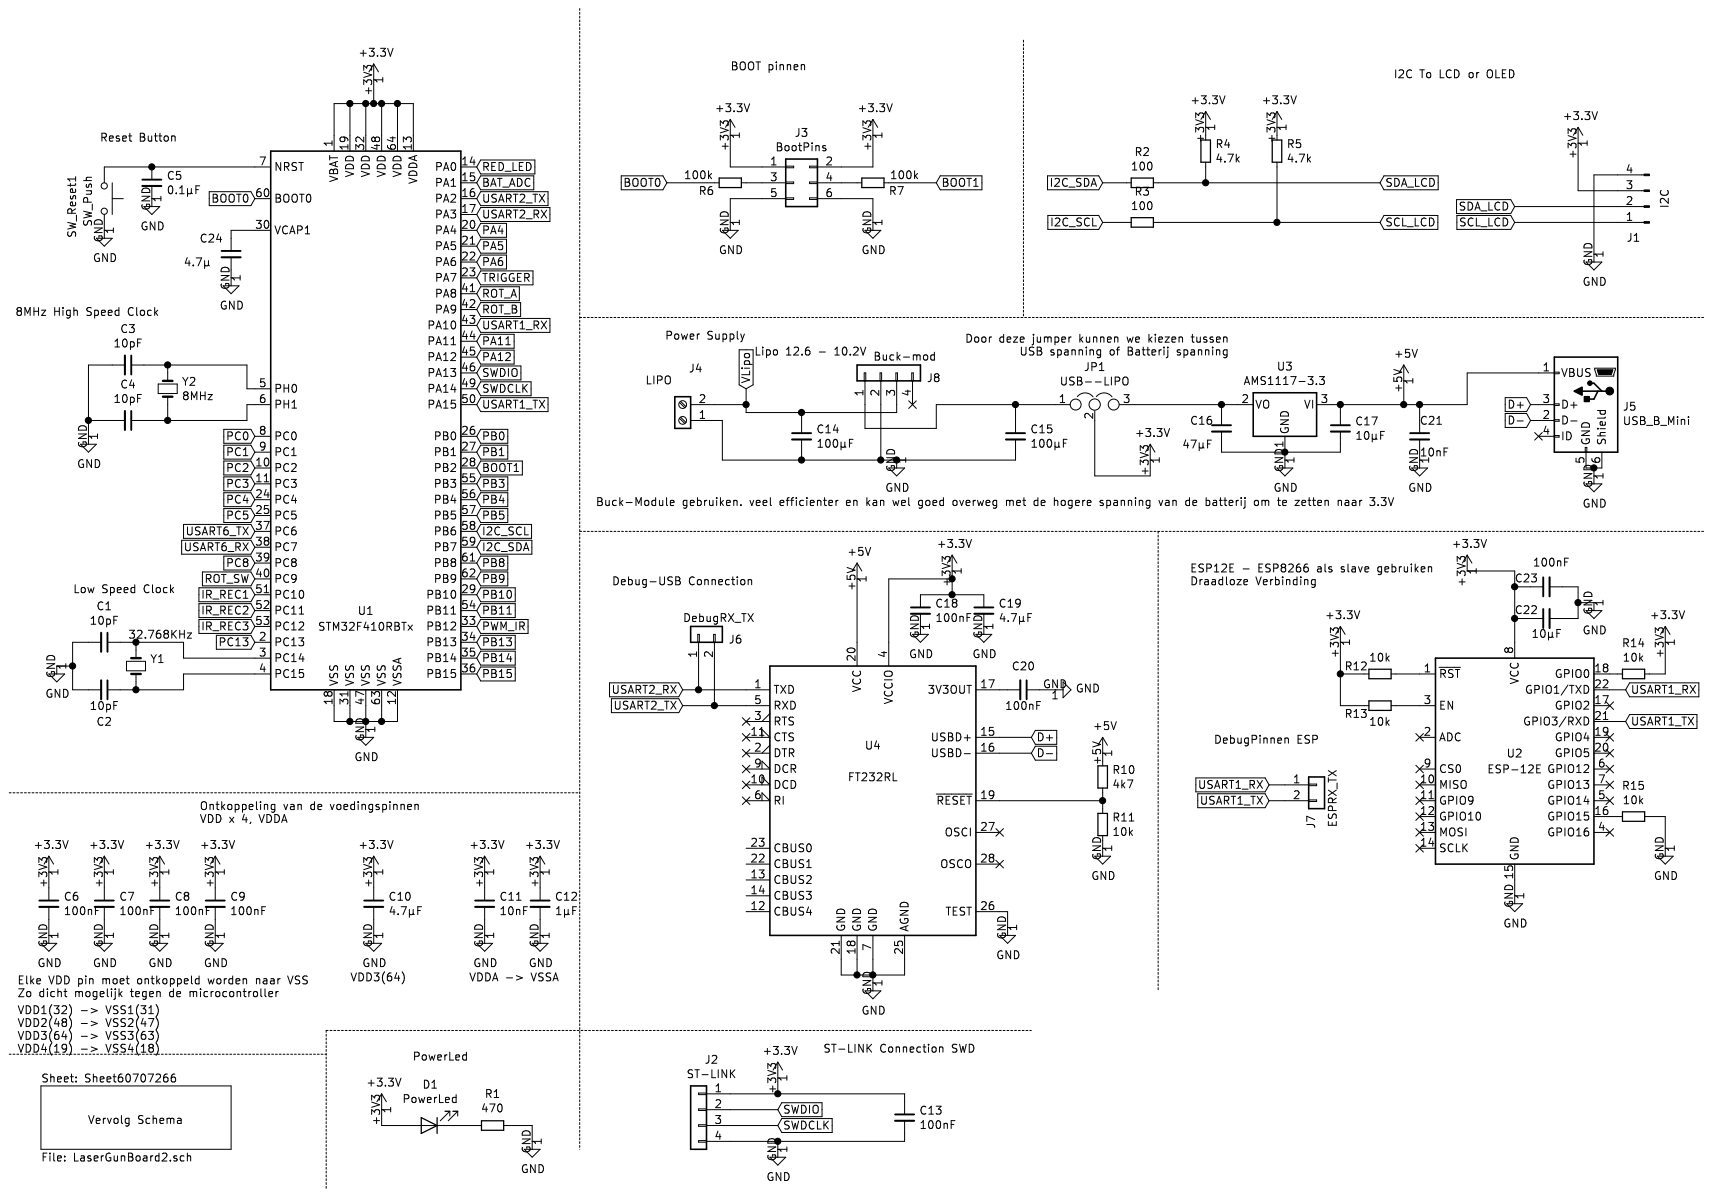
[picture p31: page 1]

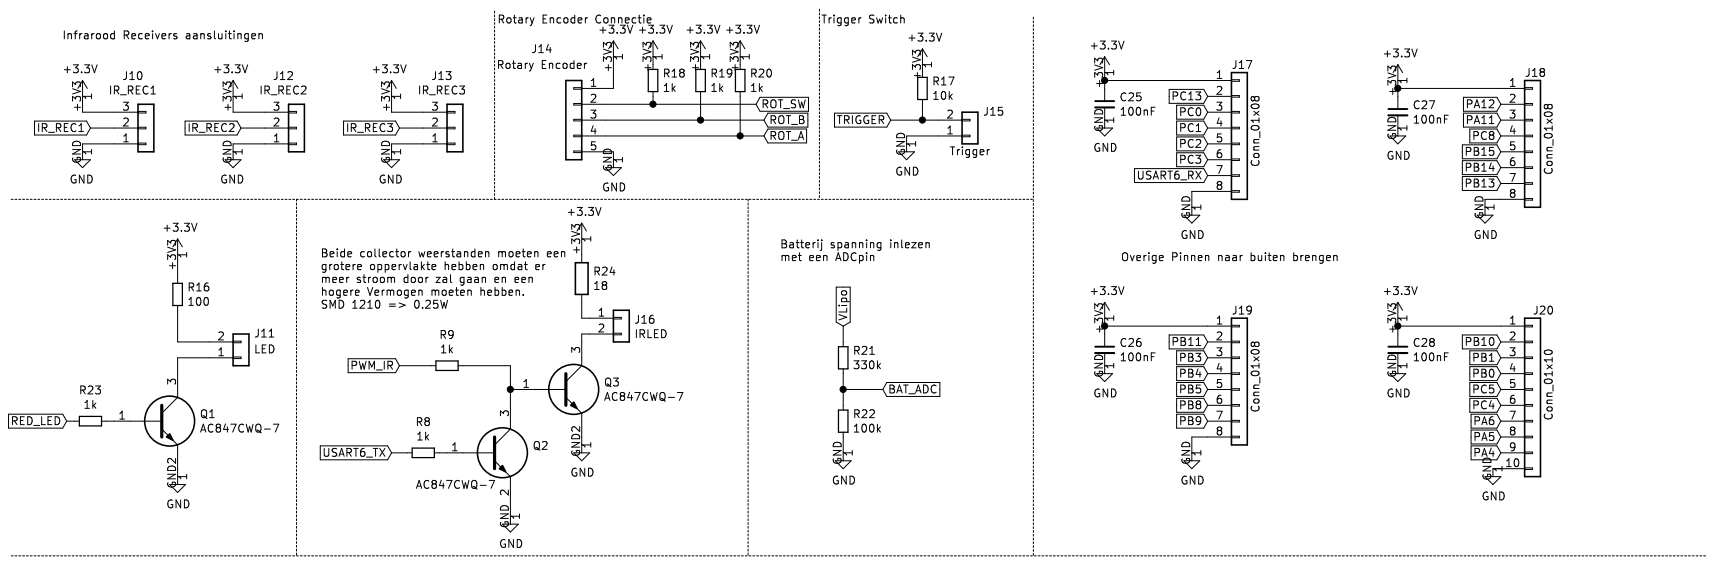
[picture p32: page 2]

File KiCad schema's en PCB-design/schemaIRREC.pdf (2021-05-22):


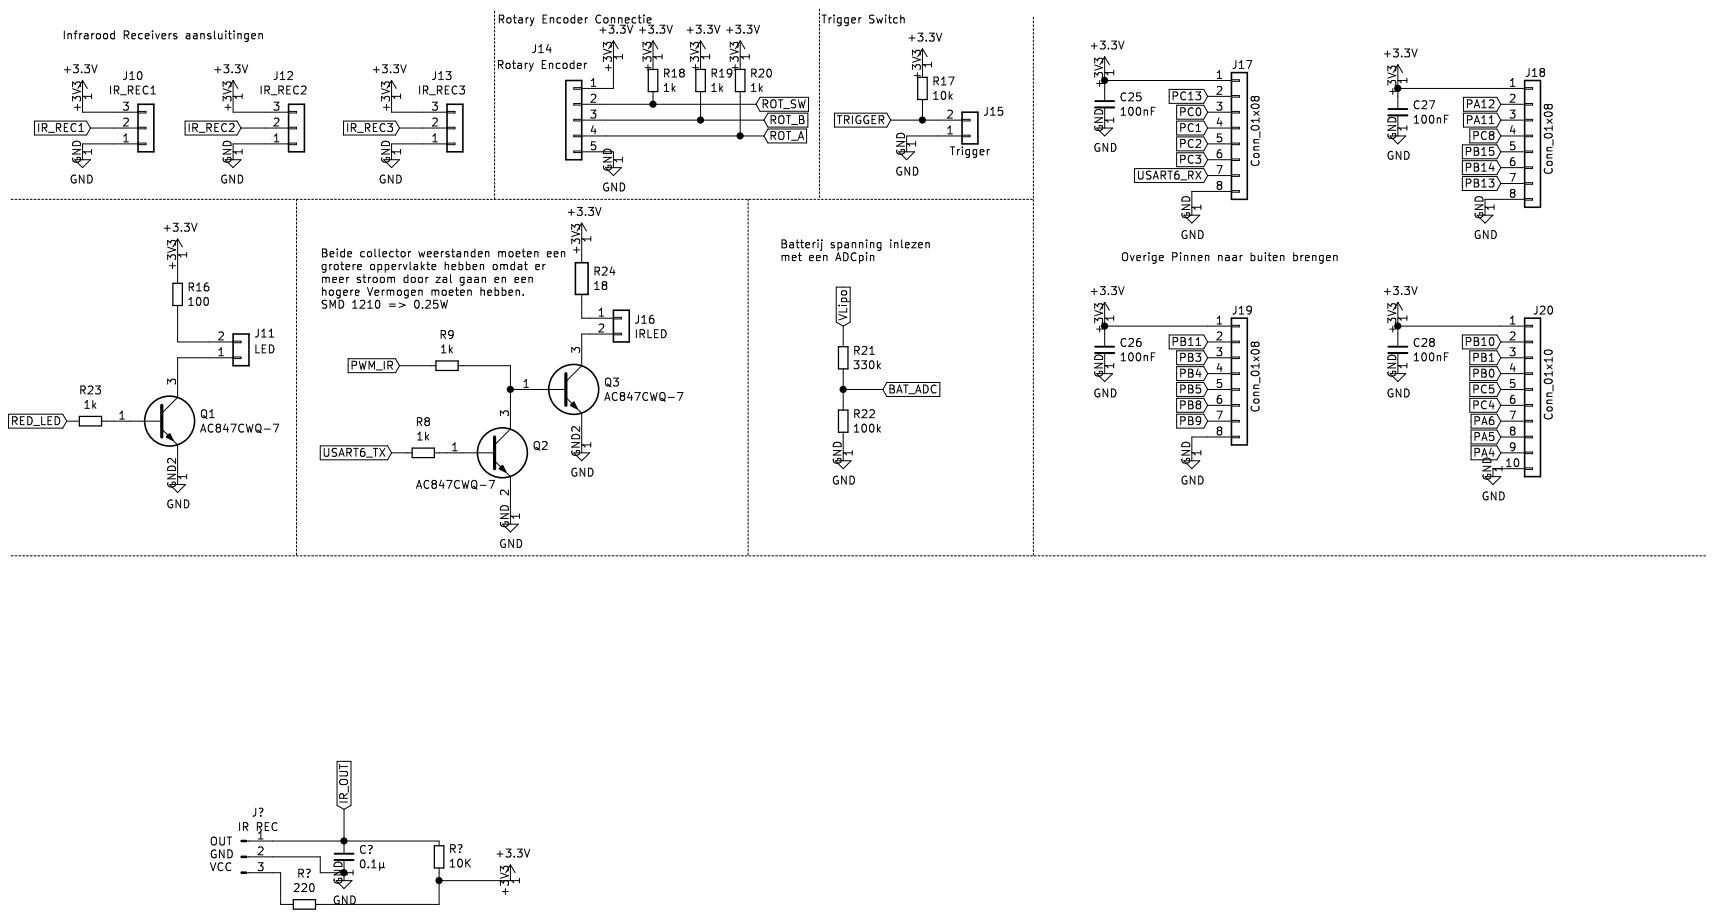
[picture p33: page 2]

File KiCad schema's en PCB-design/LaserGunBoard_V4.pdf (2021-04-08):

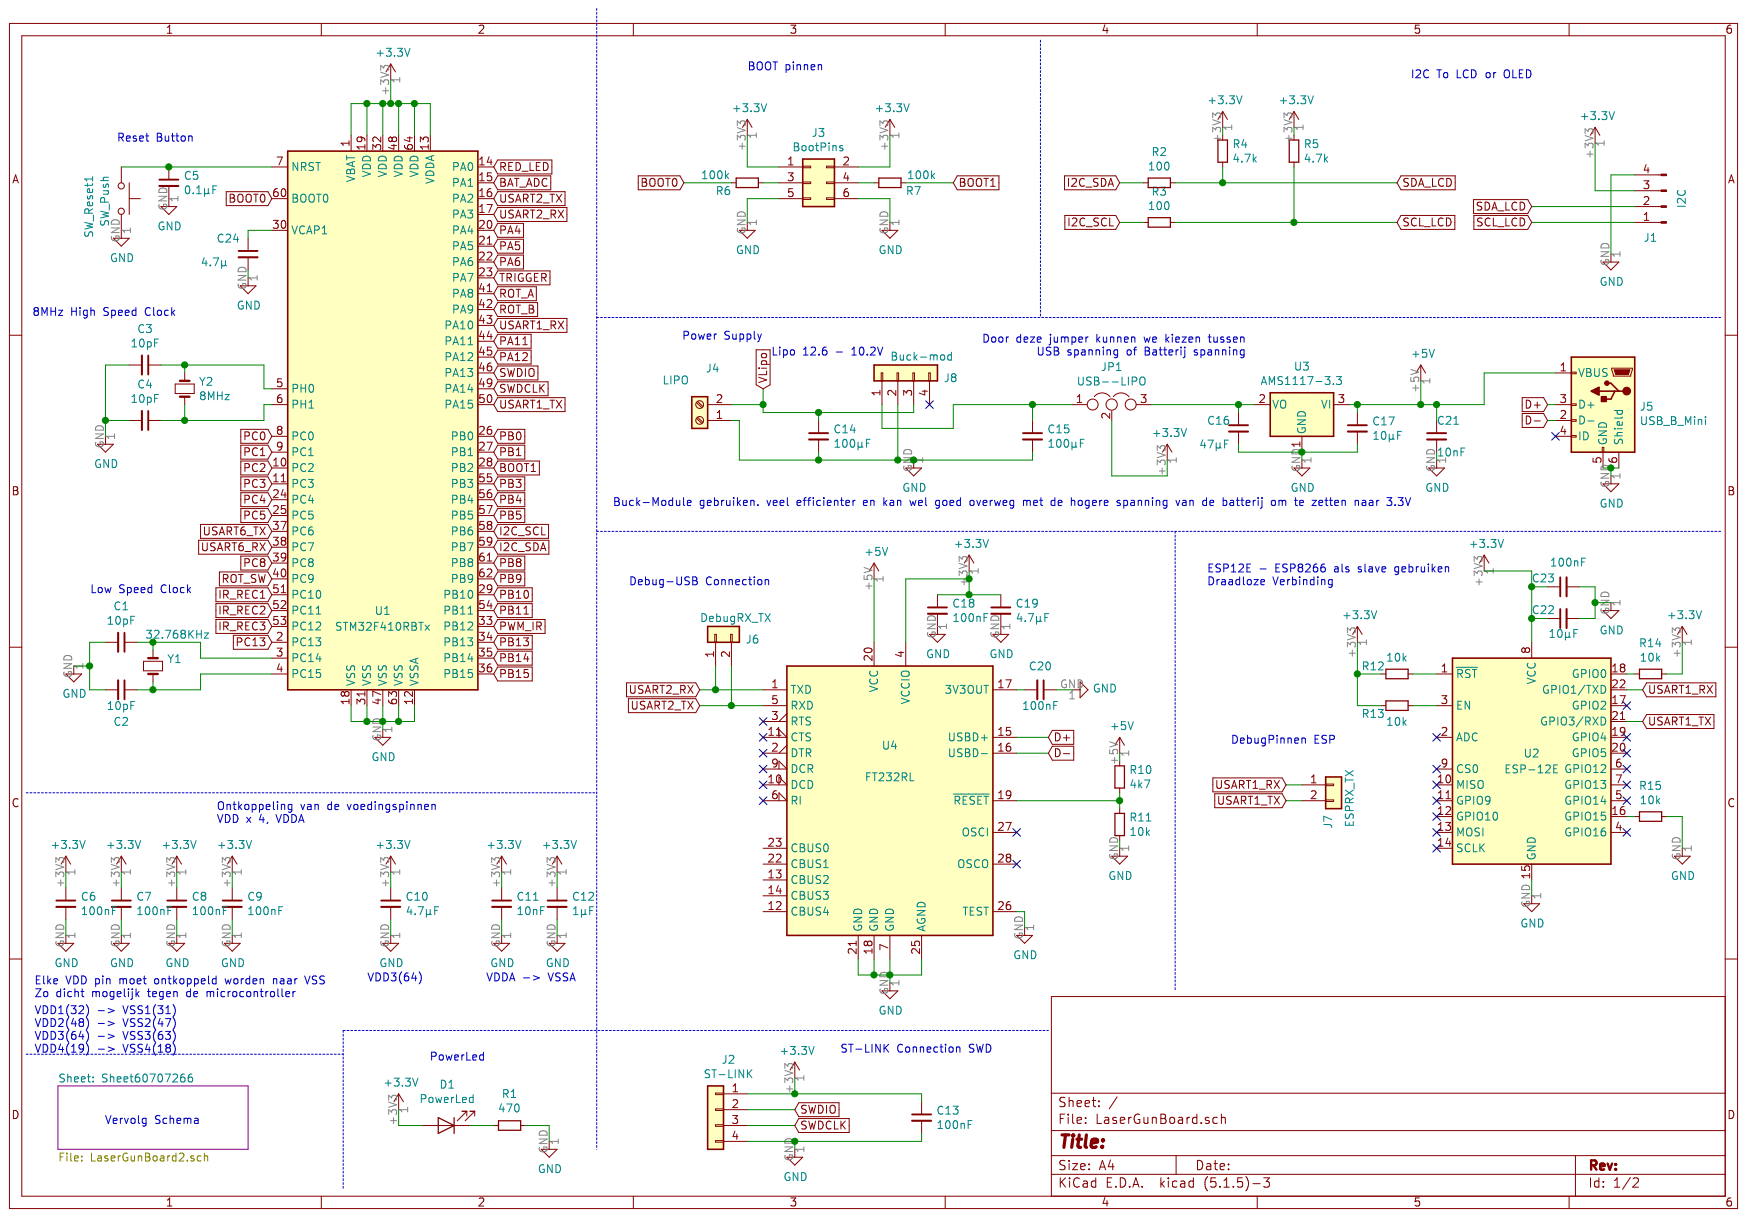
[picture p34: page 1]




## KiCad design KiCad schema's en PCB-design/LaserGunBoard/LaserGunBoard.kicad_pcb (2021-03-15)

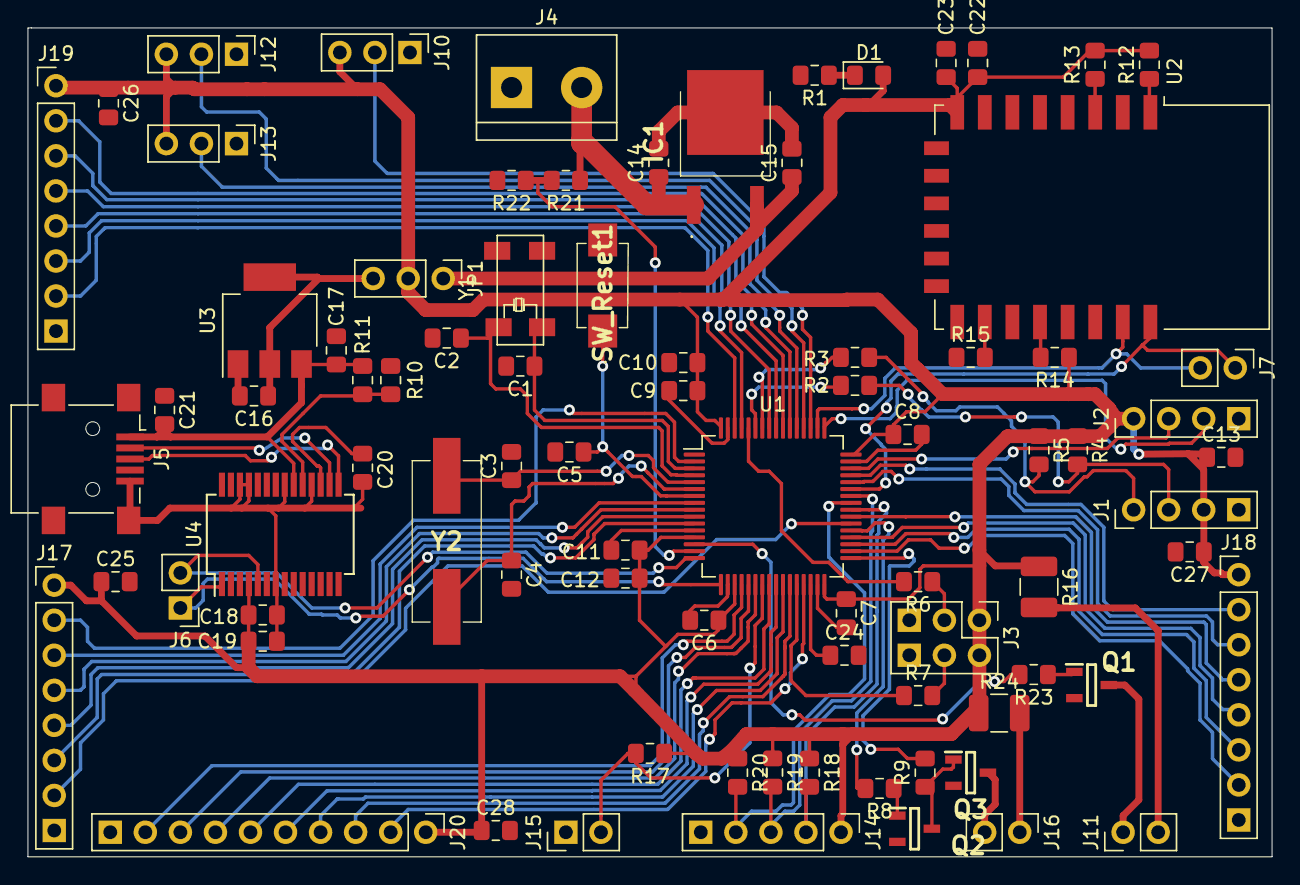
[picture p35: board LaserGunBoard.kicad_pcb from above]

Board: 2 copper layers, 90.2 x 60.1 mm, 83 parts (0 on the bottom side), 79 nets.

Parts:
C1, C2, C3, C4: 10pF; C_0805_2012Metric_Pad1.15x1.40mm_HandSolder
C5, C15: 0.1µF; C_0805_2012Metric_Pad1.15x1.40mm_HandSolder
C6, C7, C8, C9, C13, C18, C20, C23, C25, C26, C27, C28: 100nF; C_0805_2012Metric_Pad1.15x1.40mm_HandSolder
C10, C19: 4.7µF; C_0805_2012Metric_Pad1.15x1.40mm_HandSolder
C11, C21: 10nF; C_0805_2012Metric_Pad1.15x1.40mm_HandSolder
C12: 1µF; C_0805_2012Metric_Pad1.15x1.40mm_HandSolder
C14: 0.33µF; C_0805_2012Metric_Pad1.15x1.40mm_HandSolder
C16: 47µF; C_0805_2012Metric_Pad1.15x1.40mm_HandSolder
C17, C22: 10µF; C_0805_2012Metric_Pad1.15x1.40mm_HandSolder
C24: 4.7µ; C_0805_2012Metric_Pad1.15x1.40mm_HandSolder
D1: PowerLed; LED_0805_2012Metric_Pad1.15x1.40mm_HandSolder
IC1: UA78M33IKVURG3
J1: 1x4 Male Connector I2C->LCD; PinHeader_1x04_P2.54mm_Vertical
J2: ST-LINK; PinHeader_1x04_P2.54mm_Vertical
J3: BootPins; PinHeader_2x03_P2.54mm_Vertical
J4: Lipo Connectie; TerminalBlock_bornier-2_P5.08mm
J5: USB_B_Mini; USB_Mini-B_Lumberg_2486_01_Horizontal
J6: DebugRX_TX; PinHeader_1x02_P2.54mm_Vertical
J7: ESPRX_TX; PinHeader_1x02_P2.54mm_Vertical
J10: IR_REC1; PinHeader_1x03_P2.54mm_Vertical
J11: LED; PinHeader_1x02_P2.54mm_Vertical
J12: IR_REC2; PinHeader_1x03_P2.54mm_Vertical
J13: IR_REC3; PinHeader_1x03_P2.54mm_Vertical
J14: Rotary Encoder; PinHeader_1x05_P2.54mm_Vertical
J15: Trigger; PinHeader_1x02_P2.54mm_Vertical
J16: IRLED; PinHeader_1x02_P2.54mm_Vertical
J17, J18, J19: Conn_01x08; PinHeader_1x08_P2.54mm_Vertical
J20: Conn_01x10; PinHeader_1x10_P2.54mm_Vertical
JP1: Jumper_NC_Dual; PinHeader_1x03_P2.54mm_Vertical
Q1, Q2, Q3: AC847CWQ-7; SOT95P282X130-3N
R1: 470; R_0805_2012Metric_Pad1.15x1.40mm_HandSolder
R2, R3: 100; R_0805_2012Metric_Pad1.15x1.40mm_HandSolder
R4, R5: 4.7k; R_0805_2012Metric_Pad1.15x1.40mm_HandSolder
R6, R7, R22: 100k; R_0805_2012Metric_Pad1.15x1.40mm_HandSolder
R8, R9, R18, R19, R20, R23: 1k; R_0805_2012Metric_Pad1.15x1.40mm_HandSolder
R10: 4k7; R_0805_2012Metric_Pad1.15x1.40mm_HandSolder
R11, R12, R13, R14, R15, R17: 10k; R_0805_2012Metric_Pad1.15x1.40mm_HandSolder
R16: 100; R_1210_3225Metric_Pad1.42x2.65mm_HandSolder
R21: 330k; R_0805_2012Metric_Pad1.15x1.40mm_HandSolder
R24: 18; R_1210_3225Metric_Pad1.42x2.65mm_HandSolder
SW_Reset1: SW_Push; PTS636SM25FSMTRLFS
U1: STM32F410RBTx; LQFP-64_10x10mm_P0.5mm
U2: ESP-12E
U3: AMS1117-3.3; SOT-223-3_TabPin2
U4: FT232RL; SSOP-28_5.3x10.2mm_P0.65mm
Y1: 32.768KHz; 32-768kHzLOWFrequencySMDcrystal
Y2: 8MHz; FOXSDLF08020

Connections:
+3V3: C6.1, C7.1, C8.1, C9.1, C10.1, C11.1, C12.1, C13.1, C18.1, C19.1, C22.1, C23.1, C25.1, C26.1, C27.1, C28.1, D1.2, J1.3, J2.1, J3.1, J3.2, J10.3, J12.3, J13.3, J14.1, J17.1, J18.1, J19.1, J20.1, JP1.2, R4.1, R5.1, R12.2, R13.2, R14.1, R16.1, R17.1, R18.1, R19.1, R20.1, R24.1, U1.13, U1.19, U1.32, U1.48, U1.64, U2.8, U4.4
+5V: C17.1, C21.1, J5.1, R10.1, U3.3, U4.20
BAT_ADC: R21.2, R22.1, U1.15
BOOT0: R6.2, U1.60
BOOT1: R7.1, U1.28
D+: J5.3, U4.15
D-: J5.2, U4.16
GND: C1.2, C2.2, C3.2, C4.2, C5.2, C6.2, C7.2, C8.2, C9.2, C10.2, C11.2, C12.2, C13.2, C14.2, C15.2, C16.2, C17.2, C18.2, C19.2, C20.1, C21.2, C22.2, C23.2, C24.2, C25.2, C26.2, C27.2, C28.2, IC1.4, J1.4, J2.4, J3.5, J3.6, J4.1, J5.5, J5.6, J10.1, J12.1, J13.1, J14.5, J15.1, J17.8, J18.8, J19.8, J20.10, Q1.2, Q2.2, Q3.2, R1.2, R11.2, R15.1, R22.2, SW_Reset1.2, U1.12, U1.18, U1.31, U1.47, U1.63, U2.15, U3.1, U4.7, U4.18, U4.21, U4.25, U4.26
I2C_SCL: R3.2, U1.58
I2C_SDA: R2.2, U1.59
IR_REC1: J10.2, U1.51
IR_REC2: J12.2, U1.52
IR_REC3: J13.2, U1.53
unnamed: C1.1, U1.3, Y1.1
unnamed: C2.1, U1.4, Y1.2
unnamed: C3.1, U1.5, Y2.1
unnamed: C4.1, U1.6, Y2.2
unnamed: C5.1, SW_Reset1.1, U1.7
unnamed: C15.1, IC1.3, JP1.1
unnamed: C16.1, JP1.3, U3.2
unnamed: C20.2, U4.17
unnamed: C24.1, U1.30
unnamed: D1.1, R1.1
unnamed: J3.3, R6.1
unnamed: J3.4, R7.2
unnamed: J11.1, Q1.3
unnamed: J11.2, R16.2
unnamed: J16.1, R24.2
unnamed: J16.2, Q3.3
unnamed: Q1.1, R23.1
unnamed: Q2.1, R8.1
unnamed: Q2.3, Q3.1, R9.1
unnamed: R10.2, R11.1, U4.19
unnamed: R12.1, U2.1
unnamed: R13.1, U2.3
unnamed: R14.2, U2.18
unnamed: R15.2, U2.16
PA4: J20.9, U1.20
PA5: J20.8, U1.21
PA6: J20.7, U1.22
PA11: J18.3, U1.44
PA12: J18.2, U1.45
PB0: J20.4, U1.26
PB1: J20.3, U1.27
PB3: J19.3, U1.55
PB4: J19.4, U1.56
PB5: J19.5, U1.57
PB8: J19.6, U1.61
PB9: J19.7, U1.62
PB10: J20.2, U1.29
PB11: J19.2, U1.54
PB13: J18.7, U1.34
PB14: J18.6, U1.35
PB15: J18.5, U1.36
PC0: J17.3, U1.8
PC1: J17.4, U1.9
PC2: J17.5, U1.10
PC3: J17.6, U1.11
PC4: J20.6, U1.24
PC5: J20.5, U1.25
PC8: J18.4, U1.39
PC13: J17.2, U1.2
PWM_IR: R9.2, U1.33
RED_LED: R23.2, U1.14
ROT_A: J14.4, R20.2, U1.41
ROT_B: J14.3, R19.2, U1.42
ROT_SW: J14.2, R18.2, U1.40
SCL_LCD: J1.1, R3.1, R5.2
SDA_LCD: J1.2, R2.1, R4.2
SWDCLK: J2.3, U1.49
SWDIO: J2.2, U1.46
TRIGGER: J15.2, R17.2, U1.23
USART1_RX: J7.1, U1.43, U2.22
USART1_TX: J7.2, U1.50, U2.21
USART2_RX: J6.1, U1.17, U4.1
USART2_TX: J6.2, U1.16, U4.5
USART6_RX: J17.7, U1.38
USART6_TX: R8.2, U1.37
VLipo: C14.1, IC1.1, J4.2, R21.1

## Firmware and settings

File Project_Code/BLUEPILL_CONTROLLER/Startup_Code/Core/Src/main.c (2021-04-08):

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
/* Includes ------------------------------------------------------------------*/
#include "main.h"

/* USER CODE BEGIN Includes */
#include "OLED.h"
//#include "Images.h"
/* USER CODE END Includes */

/* USER CODE BEGIN PD */
#define AantalRotaties 8
/* USER CODE END PD */

I2C_HandleTypeDef hi2c1;

TIM_HandleTypeDef htim1;

UART_HandleTypeDef huart1;
UART_HandleTypeDef huart2;

/* USER CODE BEGIN PV */
#include <errno.h>
#include <sys/stat.h>
#include <sys/times.h>
#include <sys/unistd.h>
int _write(int file, char *ptr, int len) {
    HAL_StatusTypeDef xStatus;
    switch (file) {
    case STDOUT_FILENO: /*stdout*/
		xStatus = HAL_UART_Transmit(&huart2, (uint8_t*)ptr, len, HAL_MAX_DELAY);
		if (xStatus != HAL_OK) {
			errno = EIO;
			return -1;
		}
        break;
    case STDERR_FILENO: /* stderr */
		xStatus = HAL_UART_Transmit(&huart2, (uint8_t*)ptr, len, HAL_MAX_DELAY);
		if (xStatus != HAL_OK) {
			errno = EIO;
			return -1;
		}
        break;
    default:
        errno = EBADF;
        return -1;
    }
    return len;
}

volatile uint32_t tim1_cnt = 0;
volatile uint32_t direction;
/* USER CODE END PV */

void SystemClock_Config(void);
static void MX_GPIO_Init(void);
static void MX_I2C1_Init(void);
static void MX_TIM1_Init(void);
static void MX_USART2_UART_Init(void);
static void MX_USART1_UART_Init(void);
/**
  * @brief  The application entry point.
  * @retval int
  */
int main(void)
{
  /* MCU Configuration--------------------------------------------------------*/

  /* Reset of all peripherals, Initializes the Flash interface and the Systick. */
  HAL_Init();

  /* Configure the system clock */
  SystemClock_Config();

  /* Initialize all configured peripherals */
  MX_GPIO_Init();
  MX_I2C1_Init();
  MX_TIM1_Init();
  MX_USART2_UART_Init();
  MX_USART1_UART_Init();
  /* USER CODE BEGIN 2 */
  printf("Start Program \n\r");
    HAL_GPIO_WritePin(LED_GPIO_Port,LED_Pin,0);
    printf("Led aan \n\r");
    HAL_Delay(1000);

    uint8_t k;
    k = OLED_Init();
    if(k == 0)
    {
  	  HAL_GPIO_WritePin(LED_GPIO_Port,LED_Pin,1);//led uit
  	  printf("OLED IS NIET KLAAR!!!\n\r");
  	  HAL_Delay(1000);
    }
    else
    {
  	  printf("APPARAAT GEVONDEN!\r\n");
    }

    HAL_TIM_Encoder_Start(&htim1, TIM_CHANNEL_ALL);
    uint32_t rot_count = 0;
    uint8_t Select0 = 0;
    OLED_Clear();

    WelcomeScreen();

    while(HAL_GPIO_ReadPin(SW_GPIO_Port,SW_Pin) == 1 )
    {

    	//loop
    }
    OLED_Clear();
    DisplayMenu(Select0);
    OLED_UpdateScreen();



  /* USER CODE END 2 */

  /* Infinite loop */
  /* USER CODE BEGIN WHILE */
  while (1)
  {
    /* USER CODE END WHILE */

    /* USER CODE BEGIN 3 */



	  tim1_cnt = (htim1.Instance->CNT)/AantalRotaties;

	  if(rot_count != tim1_cnt)
	  {
		  if(rot_count > tim1_cnt)
		  {
			  Select0++;
			  if(Select0 > 3)
			  {
				  Select0 = 3;
			  }
		  }
		  else
		  {
			  Select0--;
			  if(Select0 < 0)
			  {
				  Select0 = 0;
			  }
		  }
		  rot_count = tim1_cnt;
		  //Displayen van een nieuw scherm want rotary waarde is veranderd
		  OLED_Fill(OLED_BLACK);
		  DisplayMenu(Select0);
		  OLED_UpdateScreen();
	  }

	  if(HAL_GPIO_ReadPin(SW_GPIO_Port, SW_Pin ) != 1 && Select0 != 0)
	  {
		  switch (Select0)
		  {
		  case 1:
			  //Optie 1 is gekozen
			  while(HAL_GPIO_ReadPin(SW_GPIO_Port,SW_Pin) == 1)
			  {
				  //Wanneer de switch button nogmaals wordt ingedrukt gaan we terug uit de optie
			  	  ShowGamePlayMenu();
			  }
			  break;
		  case 2:
			  //Optie 2 is gekozen
			  while(HAL_GPIO_ReadPin(SW_GPIO_Port,SW_Pin) == 1)
			  {
				  //Wanneer de switch button nogmaals wordt ingedrukt gaan we terug uit de optie

			  }
			  break;
		  case 3:
			  //Optie 3 is gekozen
			  while(HAL_GPIO_ReadPin(SW_GPIO_Port,SW_Pin) == 1)
			  {
				  //Wanneer de switch button nogmaals wordt ingedrukt gaan we terug uit de optie

			  }
			  break;
		  default:
			  //ERROR, mag eigenlijk niet voorkomen
			  break;
		  }

	  }
  }
  /* USER CODE END 3 */
}

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


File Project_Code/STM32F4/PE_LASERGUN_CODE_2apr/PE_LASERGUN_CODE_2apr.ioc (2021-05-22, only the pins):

Mcu.UserName=STM32F410RBTx
PA0-WKUP.GPIO_Label=RED_LED
PA0-WKUP.Signal=GPIO_Output
PA1.GPIO_Label=BAT_ADC
PA1.Signal=ADCx_IN1
PA10.Signal=USART1_RX
PA13.Signal=SYS_JTMS-SWDIO
PA14.Signal=SYS_JTCK-SWCLK
PA15.Signal=USART1_TX
PA2.Signal=USART2_TX
PA3.Signal=USART2_RX
PA7.GPIO_Label=TRIGGER
PA7.Signal=GPIO_Input
PA8.GPIO_Label=ROT_A
PA8.Signal=S_TIM1_CH1
PA9.GPIO_Label=ROT_B
PA9.Signal=S_TIM1_CH2
PB12.GPIO_Label=PWM38k_IR
PB12.Signal=S_TIM5_CH1
PB6.Signal=I2C1_SCL
PB7.Signal=I2C1_SDA
PC10.GPIO_Label=IR_REC1
PC10.Signal=GPIO_Input
PC11.GPIO_Label=IR_REC2
PC11.Signal=GPIO_Input
PC12.GPIO_Label=IR_REC3
PC12.Signal=GPIO_Input
PC14-OSC32_IN.Signal=RCC_OSC32_IN
PC15-OSC32_OUT.Signal=RCC_OSC32_OUT
PC4.Signal=S_TIM9_CH1
PC6.GPIO_Label=UART_IR
PC6.Signal=USART6_TX
PC7.Signal=USART6_RX
PC9.GPIO_Label=ROT_SW
PC9.Signal=GPIO_Input

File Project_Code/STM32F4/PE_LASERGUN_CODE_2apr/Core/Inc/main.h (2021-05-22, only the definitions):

#define RED_LED_Pin GPIO_PIN_0
#define RED_LED_GPIO_Port GPIOA
#define BAT_ADC_Pin GPIO_PIN_1
#define BAT_ADC_GPIO_Port GPIOA
#define TRIGGER_Pin GPIO_PIN_7
#define TRIGGER_GPIO_Port GPIOA
#define PWM38k_IR_Pin GPIO_PIN_12
#define PWM38k_IR_GPIO_Port GPIOB
#define UART_IR_Pin GPIO_PIN_6
#define UART_IR_GPIO_Port GPIOC
#define ROT_SW_Pin GPIO_PIN_9
#define ROT_SW_GPIO_Port GPIOC
#define ROT_A_Pin GPIO_PIN_8
#define ROT_A_GPIO_Port GPIOA
#define ROT_B_Pin GPIO_PIN_9
#define ROT_B_GPIO_Port GPIOA
#define IR_REC1_Pin GPIO_PIN_10
#define IR_REC1_GPIO_Port GPIOC
#define IR_REC2_Pin GPIO_PIN_11
#define IR_REC2_GPIO_Port GPIOC
#define IR_REC3_Pin GPIO_PIN_12
#define IR_REC3_GPIO_Port GPIOC

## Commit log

2021-03-06 aanmaken van een Readme.md file
2021-03-15 Toevoeging van alle bestanden die te maken hebben met het project
    Toevoeging van:
    -> Documenten (datasheets, foto's, logboek)
    ->KiCad (schema's en PCB designs)
    ->Project_Code (hier komt de code in die het project zal gebruiken)
    -> Test_code (hier staat code in die één voor één verschillende delen van het project gaat testen)
    [DataCom_UART_RX Run.cfg, IR_LED_TEST Run.cfg, LaserGunBoard.kicad_pcb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]
2021-04-08 extra aanvullingen
    - PCB afgewerkt + gesoldeerd
    - code geschreven voor gesoldeerd bordje
    - Afbeeldingen gemaakt voor tijdens het programma te tonen
    -
    [PE_LASERGUN_CODE_2apr Debug.cfg]
2021-05-22 Update
    alle nieuw geschreven code implementeren als ook de behuizing stl files
    [IRLEDHOLDER.stl, LEDHOLDER.stl, LaserBoard_Box.stl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]
2021-05-22 nieuwe readme
    afbeeldingen en extra info in de readme
2021-05-25 code aangepast (heel kleine update)
    [batterycover.stl]

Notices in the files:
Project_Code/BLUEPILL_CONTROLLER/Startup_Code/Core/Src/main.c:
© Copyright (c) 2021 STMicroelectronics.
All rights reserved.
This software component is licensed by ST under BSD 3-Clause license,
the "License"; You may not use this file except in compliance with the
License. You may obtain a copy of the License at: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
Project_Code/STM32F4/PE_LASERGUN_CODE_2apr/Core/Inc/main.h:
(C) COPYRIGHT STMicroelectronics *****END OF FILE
